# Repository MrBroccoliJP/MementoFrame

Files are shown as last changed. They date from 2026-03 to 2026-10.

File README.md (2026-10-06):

<p align="center">
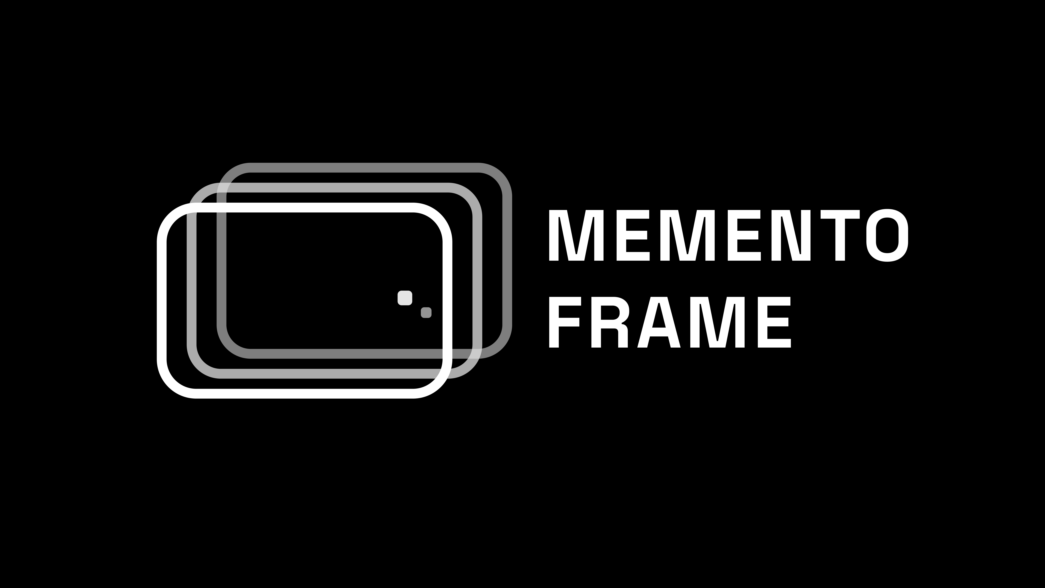
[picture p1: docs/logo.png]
MementoFrame logo
  
</p>

<h1 align="center">MementoFrame</h1>

<p align="center">
  Smart Raspberry Pi photo frame with automatic Wi-Fi/AP fallback, live Spotify integration, weather widgets, GPIO-controlled display power, and a web-based configuration portal.
</p>

<p align="center">
  
  
  
  
</p>

---

## Contents

- [Overview](#overview)
- [Features](#features)
- [Hardware Build](#hardware-build)
  - [Bill of Materials](#bill-of-materials)
  - [3D-Printed Parts](#3d-printed-parts)
  - [GPIO Connections](#gpio-connections)
  - [Wiring](#wiring)
  - [Enclosure Renders](#enclosure-renders)
- [Software Setup](#software-setup)
  - [Frontend Development Mocks](#frontend-development-mocks)
- [Technical Reference](#technical-reference)
- [Credits and License](#credits-and-license)

---

## Overview

MementoFrame is a self-contained smart photo frame platform built around a Raspberry Pi.

The system boots directly into a Chromium kiosk interface while remaining configurable from another device on the same network or on the fallback AP.

### Display Interface

<p align="center">
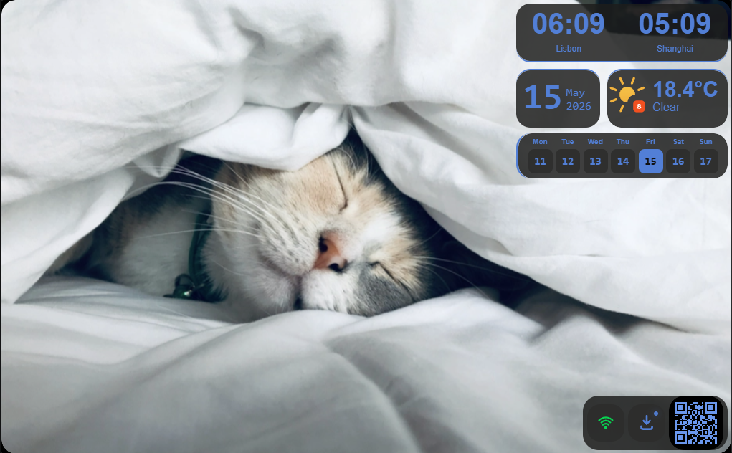
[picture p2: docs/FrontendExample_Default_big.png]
MementoFrame default full-frame photo layout with clocks, current weather, weekly calendar, system controls, and configuration QR code
  
  <br/>
  <strong>Default full-frame view</strong> — photo slideshow, clocks, current weather, weekly calendar, system status, and configuration QR code.
</p>

#### Expanded Widget Layouts

<table>
  <tr>
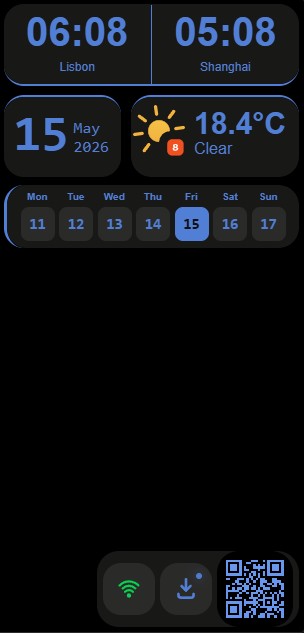
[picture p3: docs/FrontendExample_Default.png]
MementoFrame default widget layout with clocks, date, current weather, weekly calendar, and system controls
    <td align="center"><br/><strong>Default widgets</strong></td>
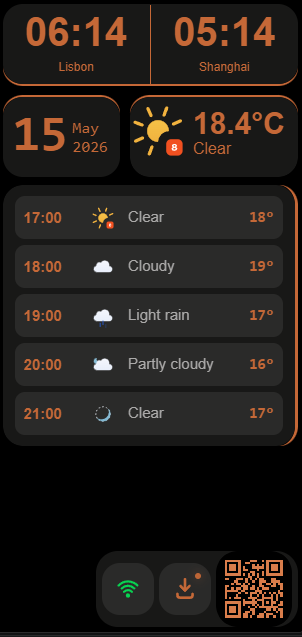
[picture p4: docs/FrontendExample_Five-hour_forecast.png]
MementoFrame expanded five-hour weather forecast layout
    <td align="center"><br/><strong>Five-hour forecast</strong></td>
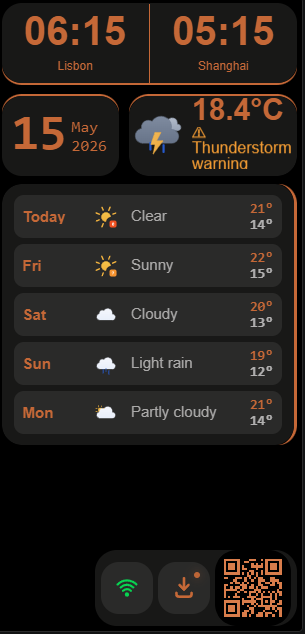
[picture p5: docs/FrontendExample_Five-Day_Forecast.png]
MementoFrame expanded five-day weather forecast layout
    <td align="center"><br/><strong>Five-day forecast*</strong></td>
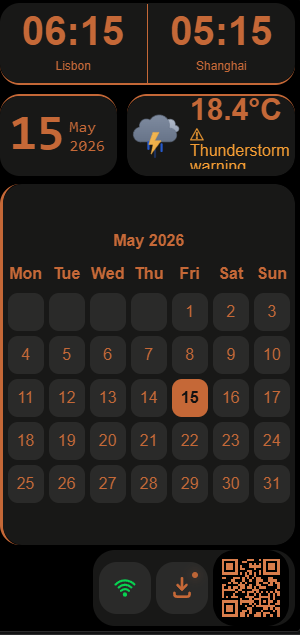
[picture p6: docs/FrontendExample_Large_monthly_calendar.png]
MementoFrame large monthly calendar layout
    <td align="center"><br/><strong>Large monthly calendar</strong></td>
  </tr>
</table>

*The mock environment provides five daily forecast entries for layout testing.
The current production configuration displays three days because that is the
forecast range available from its WeatherAPI.com plan.

#### Full Interface Examples

<p align="center">
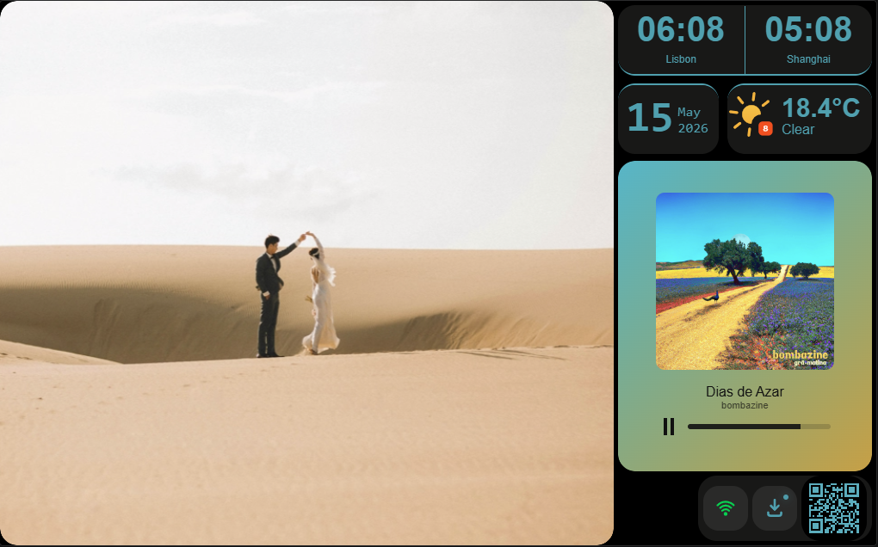
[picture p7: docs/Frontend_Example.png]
Example MementoFrame display interface showing a photo, two clocks, date, weather, Spotify playback, network status, update status, and configuration QR code
  
  <br/>
  <strong>Spotify-focused view</strong> — clocks, current weather, large Spotify playback, system status, and configuration QR code.
</p>

<p align="center">
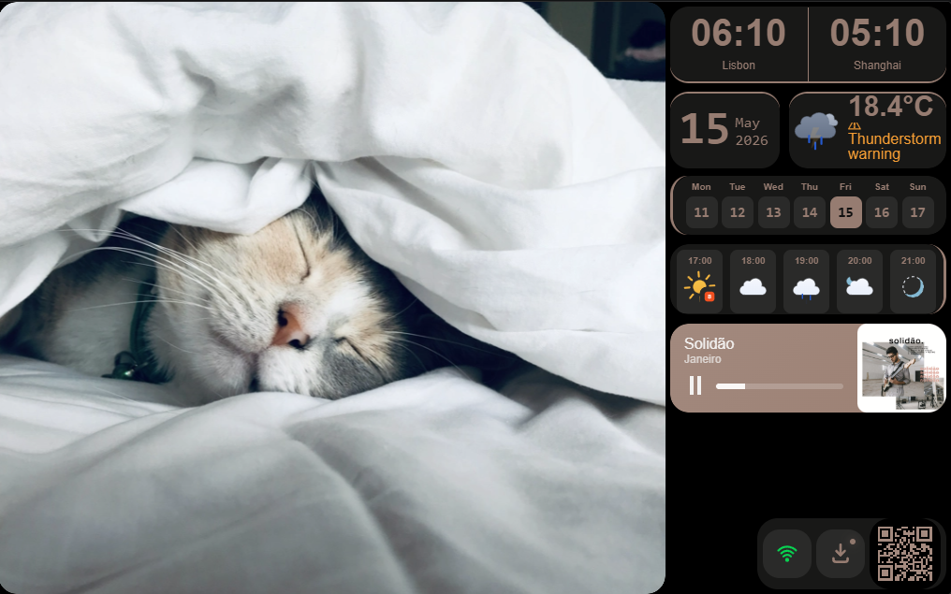
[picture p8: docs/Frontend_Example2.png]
Example MementoFrame display interface showing a photo, clocks, date, weather warning, weekly forecast, hourly forecast, Spotify playback, network status, update status, and configuration QR code
  
  <br/>
  <strong>Forecast and Spotify view</strong> — weather alert, weekly and hourly forecasts, compact Spotify playback, system status, and configuration QR code.
</p>

Displayed widgets and their layout depend on the saved configuration and the
data currently available from connected services.

#### Automatic Layout Modes

MementoFrame chooses layouts automatically according to Spotify playback,
forecast availability, and its current display cycle:

| State | Modes shown |
|---|---|
| Normal display | Weekly calendar by default; compact five-hour forecast once during each five-minute cycle when forecast data is available. |
| Spotify playing | Large Spotify player by default; once during each five-minute cycle it changes to compact Spotify with the weekly calendar and compact five-hour forecast. |
| Expanded mode | Starts after a 30-minute interval and remains active for up to 10 minutes. It rotates between the large five-hour forecast, large five-day forecast, and large monthly calendar; Spotify playback temporarily interrupts it. |
| Forecast unavailable | Forecast modes are skipped and the corresponding weekly or monthly calendar remains visible instead. |

The photo slideshow, clocks, date, current-weather card, network status, update
status, and configuration QR code continue to appear wherever the selected
layout has space for them. The interface also swaps sides once per hour to vary
the presentation and reduce prolonged use of the same screen area.

In the Classic, Classic Flat, and Minimal Sidebar themes, interface accent
colors cycle automatically through a randomized palette. Classic Flat keeps
the Classic layout and materials while removing the colored panel outlines.
When Spotify is playing, the player derives a primary and companion color from
the current album art and applies that palette across the interface.

### Project Photos

<table>
  <tr>
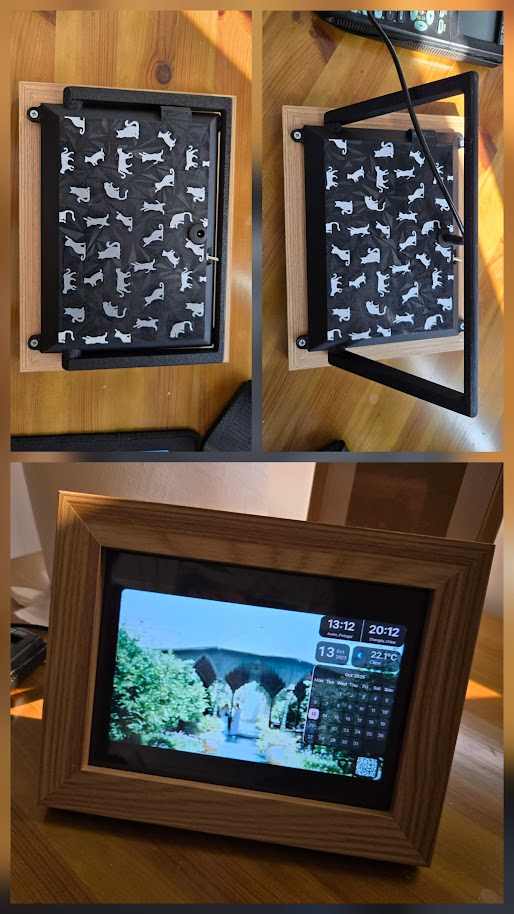
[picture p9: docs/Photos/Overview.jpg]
MementoFrame front and rear overview
    <td align="center"><br/><strong>Front and rear overview</strong></td>
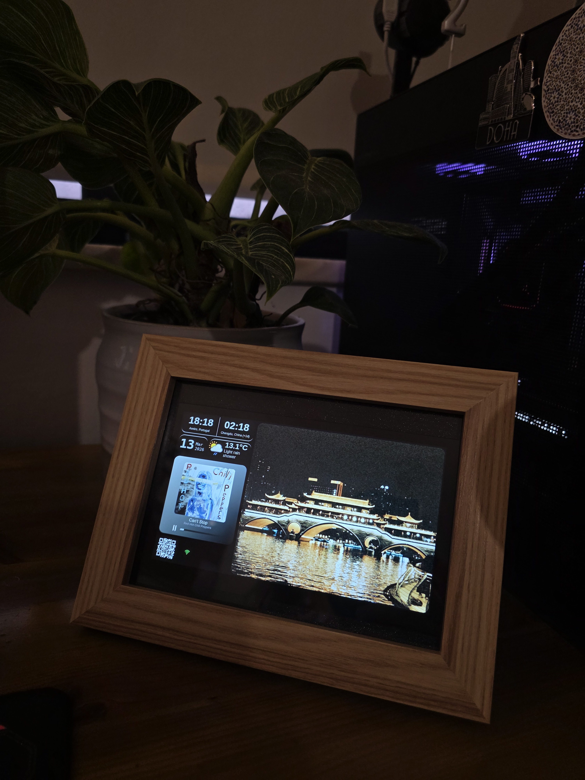
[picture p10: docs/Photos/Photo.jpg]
MementoFrame displaying a photo with widgets and Spotify controls
    <td align="center"><br/><strong>MementoFrame in use</strong></td>
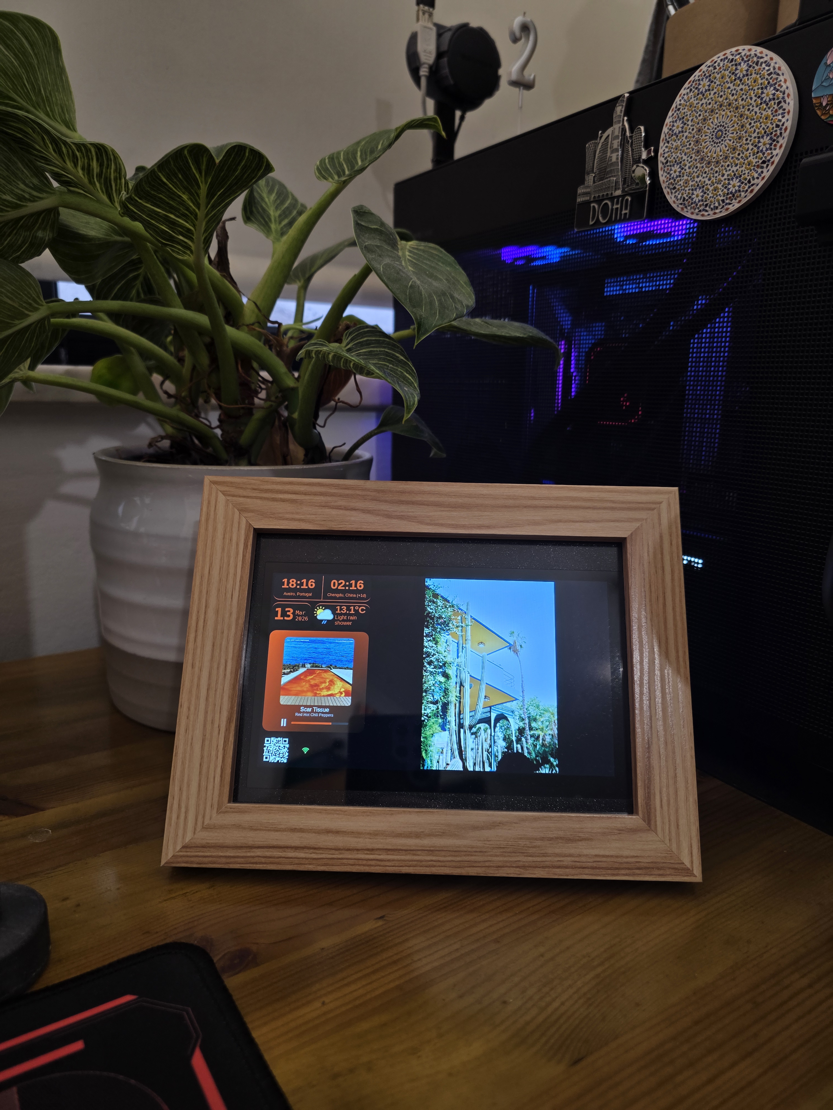
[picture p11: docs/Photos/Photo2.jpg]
MementoFrame displaying a portrait photo with widgets and Spotify controls
    <td align="center"><br/><strong>Portrait photo display</strong></td>
  </tr>
</table>

---

## Features

### Photo Management

- Multi-file photo uploads
- Automatic EXIF rotation handling
- Automatic WebP conversion
- Thumbnail generation
- Persistent slideshow ordering
- Dynamic display reloads via SSE

### Network Management

- Fully managed by NetworkManager
- Automatic fallback AP mode
- SSID: `MementoFrame`
- AP gateway: `192.168.4.1`
- Automatic reconnect probing
- Runtime-only configuration PIN protection

### Display Features

- Fullscreen Chromium kiosk mode
- GPIO-controlled display power
- GPIO brightness pulse control
- Auto on/off schedules
- Dual timezone clocks
- Selectable Classic, Classic Flat, and Minimal Sidebar display themes
- Filled, flat, line, or recolored monochrome forecast icons; current weather and warnings remain filled
- Weather widget with selectable Open-Meteo, WeatherAPI.com, or Google Weather providers
- Spotify album art and playback state

### Weather Providers

WeatherAPI.com was MementoFrame's original and default weather provider. After
inconsistent and inaccurate results were observed for the locations used during
development, Open-Meteo and Google Weather were added as alternatives, with
Open-Meteo becoming the default for new installations. The provider adapters
normalize their different responses into the original MementoFrame weather
flow, allowing the existing current-weather, hourly-forecast, daily-forecast,
UV-index, and icon-rendering code to work across all three providers.

### Updates

- GitHub Releases-based update checks
- Manual update from the configuration portal
- Optional automatic update window
- Persistent user data preservation
- Post-reboot health validation

---

## Hardware Build

### Bill of Materials

The following frame, electronic, and display components are used for one MementoFrame.
Printed parts and their fasteners are listed separately in the next section.

| Component | Quantity | Specification / purpose |
|---|---:|---|
| Wooden photo frame | 1 | Store-bought frame for a 130 × 180 mm (13 × 18 cm, approximately 5 × 7 inch) photo. The supplied 3D files are designed around the dimensions documented below. |
| Raspberry Pi 3B+ | 1 | Main computer running the MementoFrame software. |
| EP-0170 display | 1 | Commonly sold as the GeeekPi 7-inch Raspberry Pi LCD; 1024 × 600 IPS panel. |
| DS3231 RTC module | 1 | Battery-backed real-time clock for retaining the time while disconnected from power. |
| Mini-560 DC-DC buck converter | 2 | Step-down converters configured for 12 V input and 5 V output: one for the display and one for the Raspberry Pi. |
| DC power-filter board | 1 | Filters the incoming DC supply before it reaches the converters and electronics. |
| 2.1 mm panel-mount female DC barrel jack | 1 | Panel-mount power input; select a size matching the power-supply plug. |
| Solderable Micro-USB plug | 1 | Connects the 5 V power-board output to the Raspberry Pi power input. |
| FPC HDMI cable | 1 | Low-profile HDMI connection between the Raspberry Pi and display. |
| Right-angle HDMI-to-FPC adapter | 1 | Display-side adapter. |
| HDMI-to-FPC adapter | 1 | Raspberry Pi-side adapter. |
| MTS-102 mini toggle switch | 1 | Manual power/control switch. |
| SPST DIP or slide switch | 1 (optional) | Initial-setup override that keeps the display enabled before GPIO control is active. |
| Hook-up wire | As required | Power and signal wiring between the boards, connectors, and switch. |

The two HDMI-to-FPC adapters and FPC cable must use the same pin count and
contact orientation. Before connecting the Raspberry Pi or display, adjust
both Mini-560 converters and verify a stable 5 V output with a multimeter.

### 3D-Printed Parts

MementoFrame uses six 3D-printed part designs. One complete assembly requires
one print of each design. Ready-to-print STL files are in [`hardware/stl`](hardware/stl),
and the editable Fusion 360 archive is available at
[`hardware/source/MementoFrame.f3z`](hardware/source/MementoFrame.f3z).

#### Wooden Frame Compatibility

The supplied 3D files were designed for a store-bought wooden frame intended
for a 130 × 180 mm (13 × 18 cm, approximately 5 × 7 inch) photo. A different frame can be used to suit individual
needs or preferences, but the fit must be checked and the 3D models may need to
be adjusted accordingly.

| Measurement | Reference frame |
|---|---:|
| Nominal photo size | 130 × 180 mm (13 × 18 cm / 5 × 7 inches) |
| Visible front opening | Approximately 120 × 170 mm (not important due to the display bezel*) |
| Outside wooden-frame dimensions | 218 × 169 mm |
| Approximate front wooden bezel | 24.25 mm |
| Rear opening for inserting the photo/display | 130 × 181 mm |
| Approximate rear bezel | 20 mm |
| Minimum rear bezel required for back-cover mounting points | 10 mm |
| Overall frame depth | 18 mm |
| Available internal depth | 9.5 mm |
| Glass thickness | 1.6 mm |

*3D changes to the display mounting plate would need to be done to accomodate a different outer frame.

The original glass is reused. The display sits against the glass, with the
printed assembly installed behind it. The original back is discarted.

> **Wall-mounting limitation:** The current design is intended for use with
> the printed stand. It cannot sit flush against a wall because the DC barrel
> jack protrudes from the rear. Wall mounting requires changes to the 3D files
> to relocate or recess the power connector and provide suitable mounting
> points.

#### Assembly Layout

<p align="center">
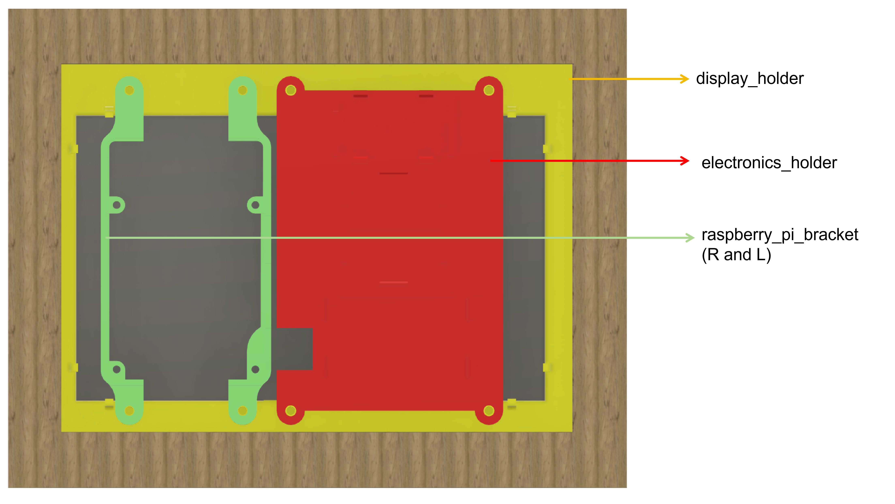
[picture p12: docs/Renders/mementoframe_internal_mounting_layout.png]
MementoFrame internal mounting layout showing the display holder, electronics holder, and Raspberry Pi brackets
  
  <br/>
  <strong>Internal mounting layout</strong> — display holder, electronics holder, and left/right Raspberry Pi brackets.
</p>

The display is secured by integrated clips on the 3D-printed display holder.
The holder uses different side offsets to compensate for the display's uneven
physical bezel and center the visible LCD area within the wooden frame opening.
Display orientation is therefore important: align the thicker and thinner
bezel edges with the corresponding sides of the holder. Before engaging all
clips or closing the frame's metal tabs, inspect the frame from the front and
confirm that the active LCD area—not the outside edge of the display board—is
centered in the visible opening.

The display holder is then retained inside the wooden frame by the frame's
original metal tabs—the same tabs normally used to hold the glass, photo, and
backing board. The display holder therefore needs no adhesive or additional
fasteners of its own.

The back cover sits over the completed electronics assembly and is secured
directly to the rear wooden bezel with four 3 × 10 mm wood screws.

The DC power-filter board, DS3231 RTC module, and both Mini-560 DC-DC buck
converters press-fit into their dedicated positions on the 3D-printed
electronics holder; they do not require separate mounting screws.
The Raspberry Pi itself does not require screws; the left and right brackets clamp the board securely in place.

<p align="center">
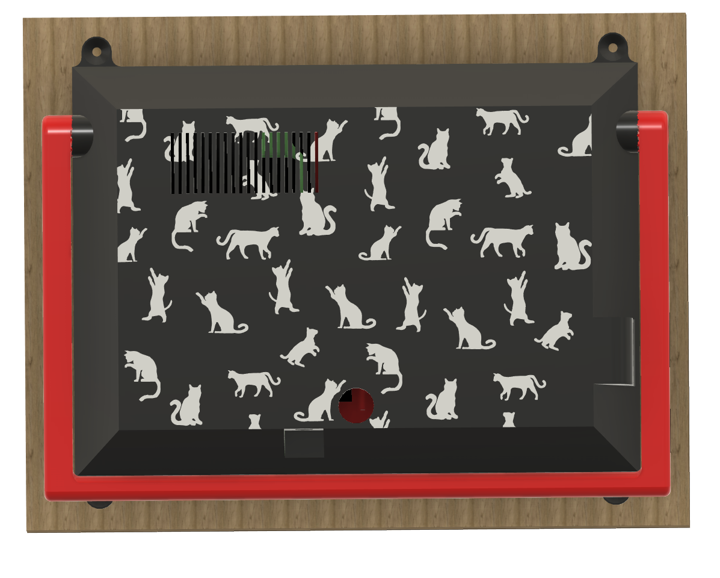
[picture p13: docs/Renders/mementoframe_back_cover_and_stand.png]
MementoFrame rear assembly showing the back cover and stand
  
  <br/>
  <strong>Rear assembly</strong> — installed back cover and stand.
</p>

#### Assembly Hardware

In addition to the printed parts, one complete assembly requires:

| Fastener | Quantity | Used for |
|---|---:|---|
| M3 × 10 mm screws | 8 | Electronics holder and left/right Raspberry Pi brackets |
| 3 × 10 mm wood screws | 4 | Securing the back cover to the wooden frame |
| 5 × 10 mm wood screws or M5 × 10 mm screws | 2 | Attaching the stand |

Use the fastener type appropriate for the stand mounting holes and the material
the screws engage. Do not overtighten screws against the printed parts.

#### Parts to Print

| Part | STL file | Quantity | Purpose |
|---|---|---:|---|
| Display holder | [`display_holder.stl`](hardware/stl/display_holder.stl) | 1 | Holds the display with integrated clips. Its side offsets compensate for the uneven display bezel and center the visible LCD. The complete holder is retained by the wooden frame's original metal tabs. |
| Electronics holder | [`electronics_holder.stl`](hardware/stl/electronics_holder.stl) | 1 | Press-fit mounting for both DC buck converters, the power-filter board, and the RTC module; also organizes the wiring. |
| Raspberry Pi brackets | [`raspberry_pi_bracket_L.stl`](hardware/stl/raspberry_pi_bracket_L.stl) and [`raspberry_pi_bracket_R.stl`](hardware/stl/raspberry_pi_bracket_R.stl) | 1 left, 1 right | Secures the Raspberry Pi while preserving connector access and airflow. |
| Back cover | [`back_cover.stl`](hardware/stl/back_cover.stl) | 1 | Protects the electronics and wiring while providing ventilation and access openings. Secures to the wooden frame with four 3 × 10 mm wood screws. |
| Stand | [`stand.stl`](hardware/stl/stand.stl) | 1 | Supports the frame at a suitable viewing angle and attaches with two screws. |

### GPIO Connections

| GPIO | Purpose |
|---:|---|
| GPIO 20 | Brightness UP pulse |
| GPIO 21 | Brightness DOWN pulse |
| GPIO 26 | Screen power enable |

### Wiring

The diagram below shows the power distribution, display controls, RTC wiring,
and HDMI connection. The completed wiring photo can be used as a reference for
component placement and cable routing.

<p align="center">
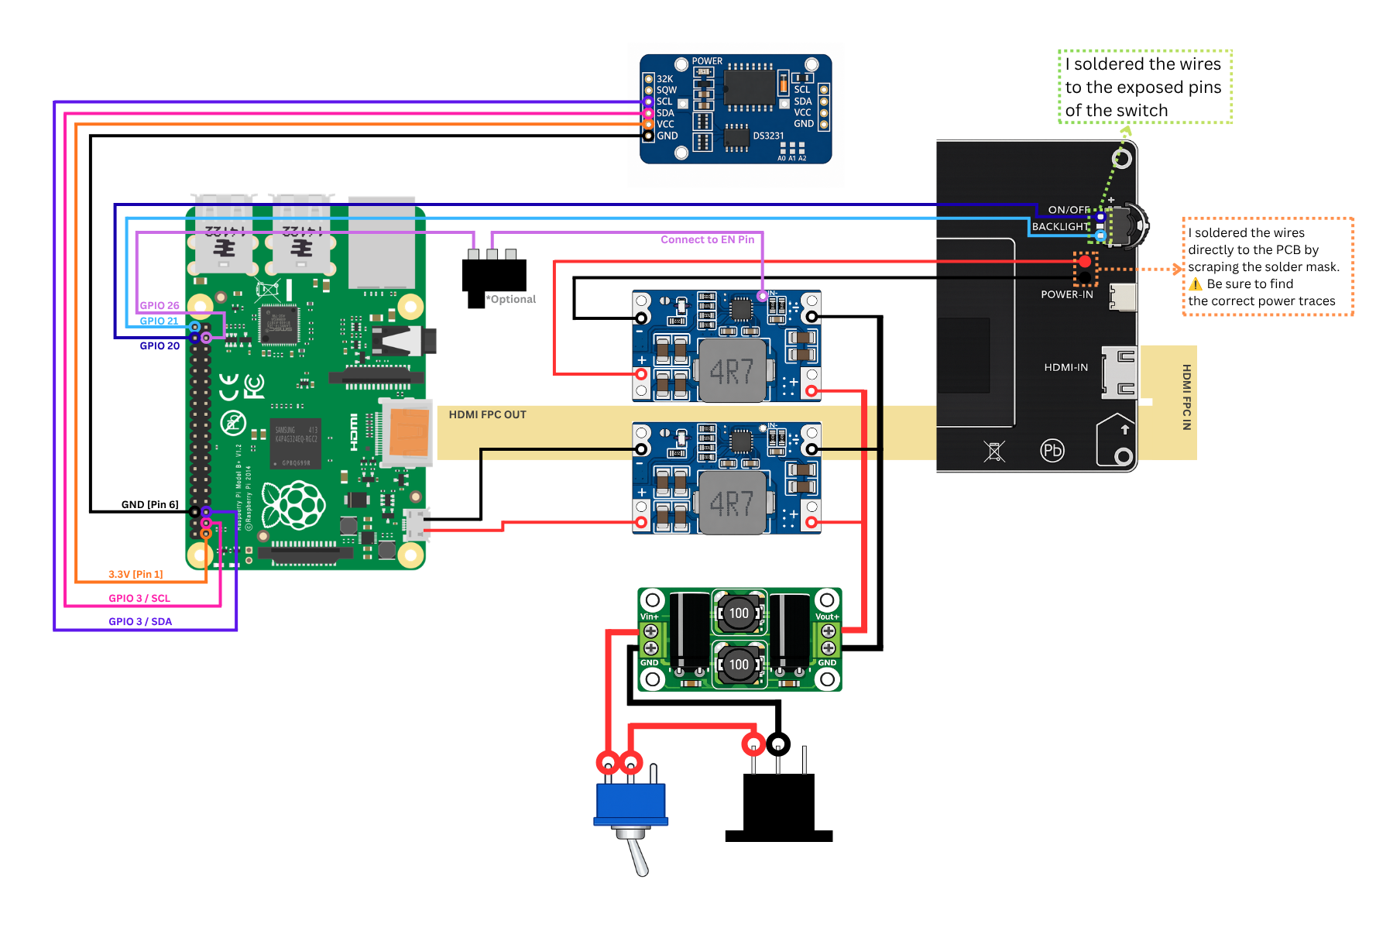
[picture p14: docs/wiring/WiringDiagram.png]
MementoFrame wiring diagram for the Raspberry Pi, display, RTC, buck converters, optional display-enable switch, power filter, toggle switch, and barrel jack
  
  <br/>
  <strong>Wiring diagram</strong>
</p>

<p align="center">
  Completed MementoFrame internal wiring and electronics installation
  <br/>
  <strong>Completed wiring and component placement</strong>
</p>

#### Connection Summary

| Connection | Details |
|---|---|
| Power input | The 12 V supply enters through the barrel jack and MTS-102 switch, then passes through the DC power-filter board. |
| 5 V power | The filtered 12 V input feeds both Mini-560 converters. One converter powers the Raspberry Pi and the other powers the display. |
| RTC | Connect the DS3231 to Raspberry Pi 3.3 V, ground, I²C SDA, and I²C SCL. |
| Display controls | Connect display power and brightness controls to GPIO 26, GPIO 20, and GPIO 21 as labelled in the diagram. |
| Optional display-enable override | Install the optional DIP/slide switch in the display-enable circuit as shown. It keeps the display powered during initial assembly and software installation. |
| Video | The FPC HDMI cable links the Raspberry Pi HDMI output to the display HDMI input through the two HDMI-to-FPC adapters. |

#### Optional First-Boot Display Override

The display-enable GPIO starts inactive before the MementoFrame service is
installed and running, which would otherwise leave the screen switched off.
The optional DIP/slide switch provides a manual override that keeps the display
enabled while assembling the frame, installing the operating system, and
setting up the software.

Close the override switch for initial setup. Once GPIO display control is
installed and confirmed to work, open the switch to return control to the
Raspberry Pi. The switch can remain installed for future troubleshooting.

> **Important:** Disconnect power while assembling the wiring. Set and verify
> both buck-converter outputs at 5 V before connecting the Raspberry Pi or
> display, and confirm polarity with a multimeter. The display control wires
> are soldered directly to exposed PCB points, and trace locations can differ
> between display revisions. Trace them from the USB-C connector and verify the
> circuit before soldering. Never scrape, probe, or solder an energized PCB.

### Enclosure Renders

<table>
  <tr>
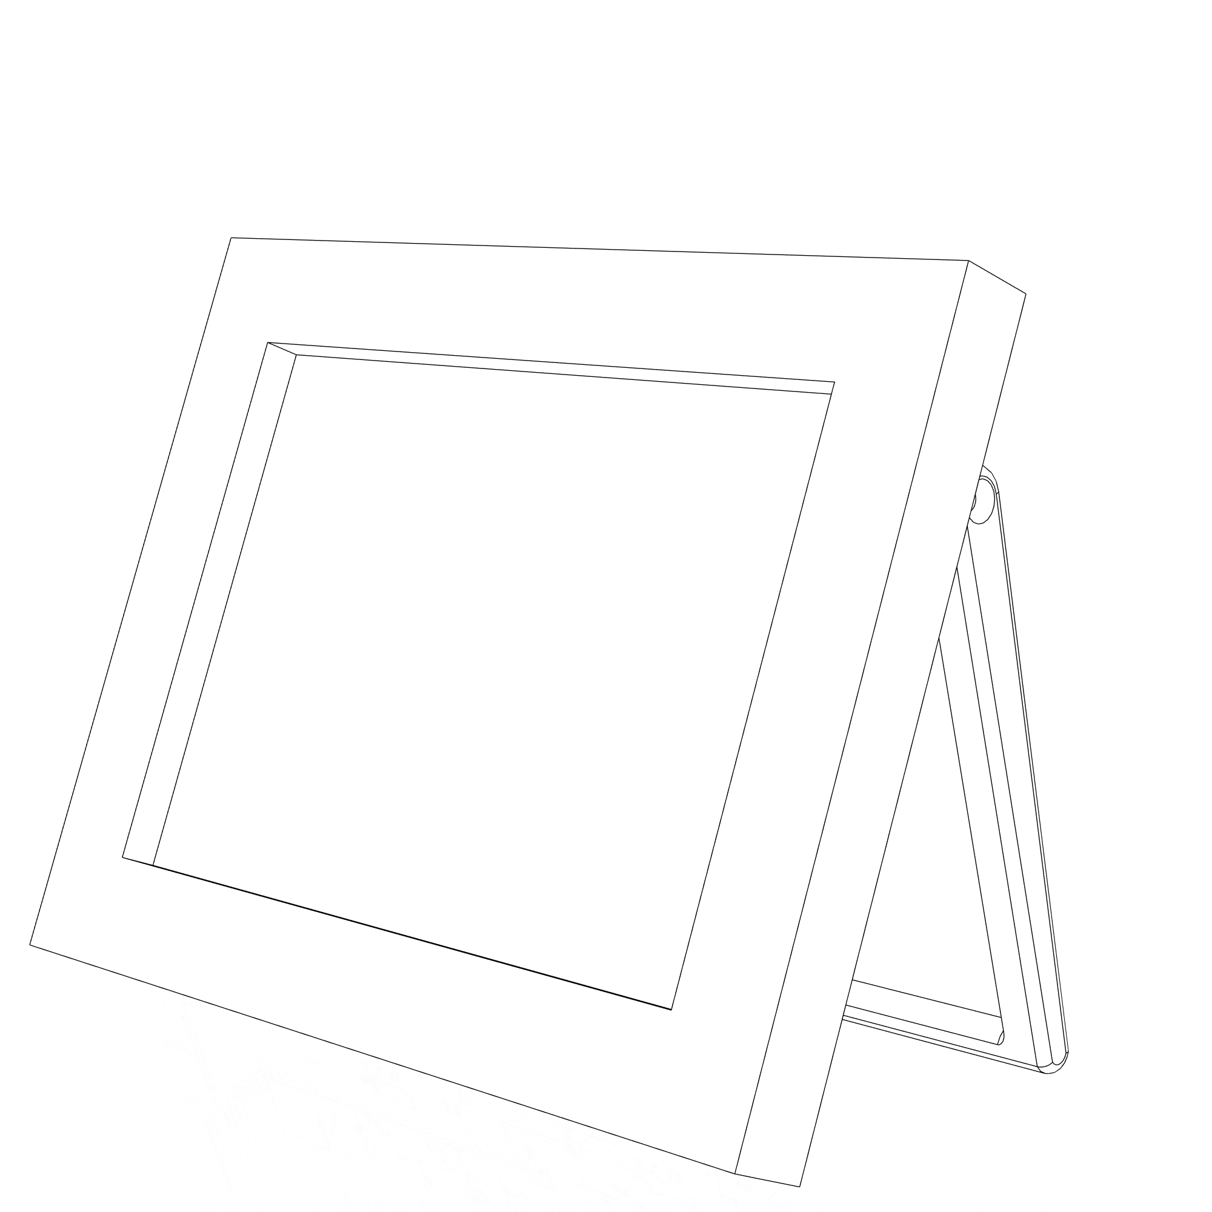
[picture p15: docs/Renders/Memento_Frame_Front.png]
MementoFrame front view
    <td align="center"><br/><strong>Front</strong></td>
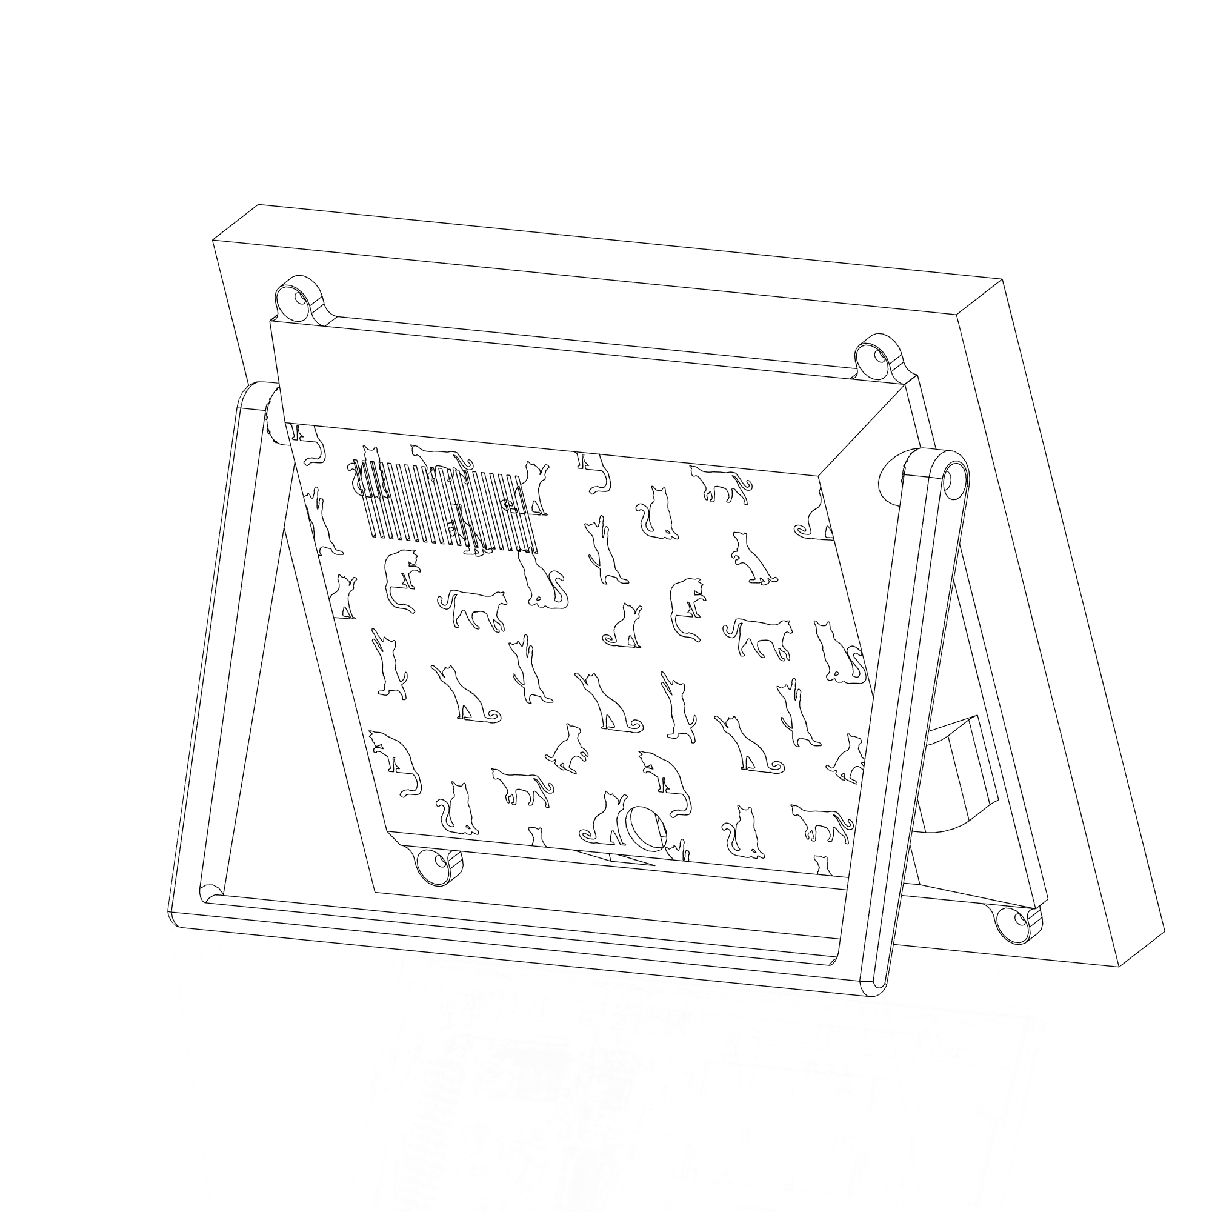
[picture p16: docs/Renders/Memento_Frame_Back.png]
MementoFrame back view
    <td align="center"><br/><strong>Back</strong></td>
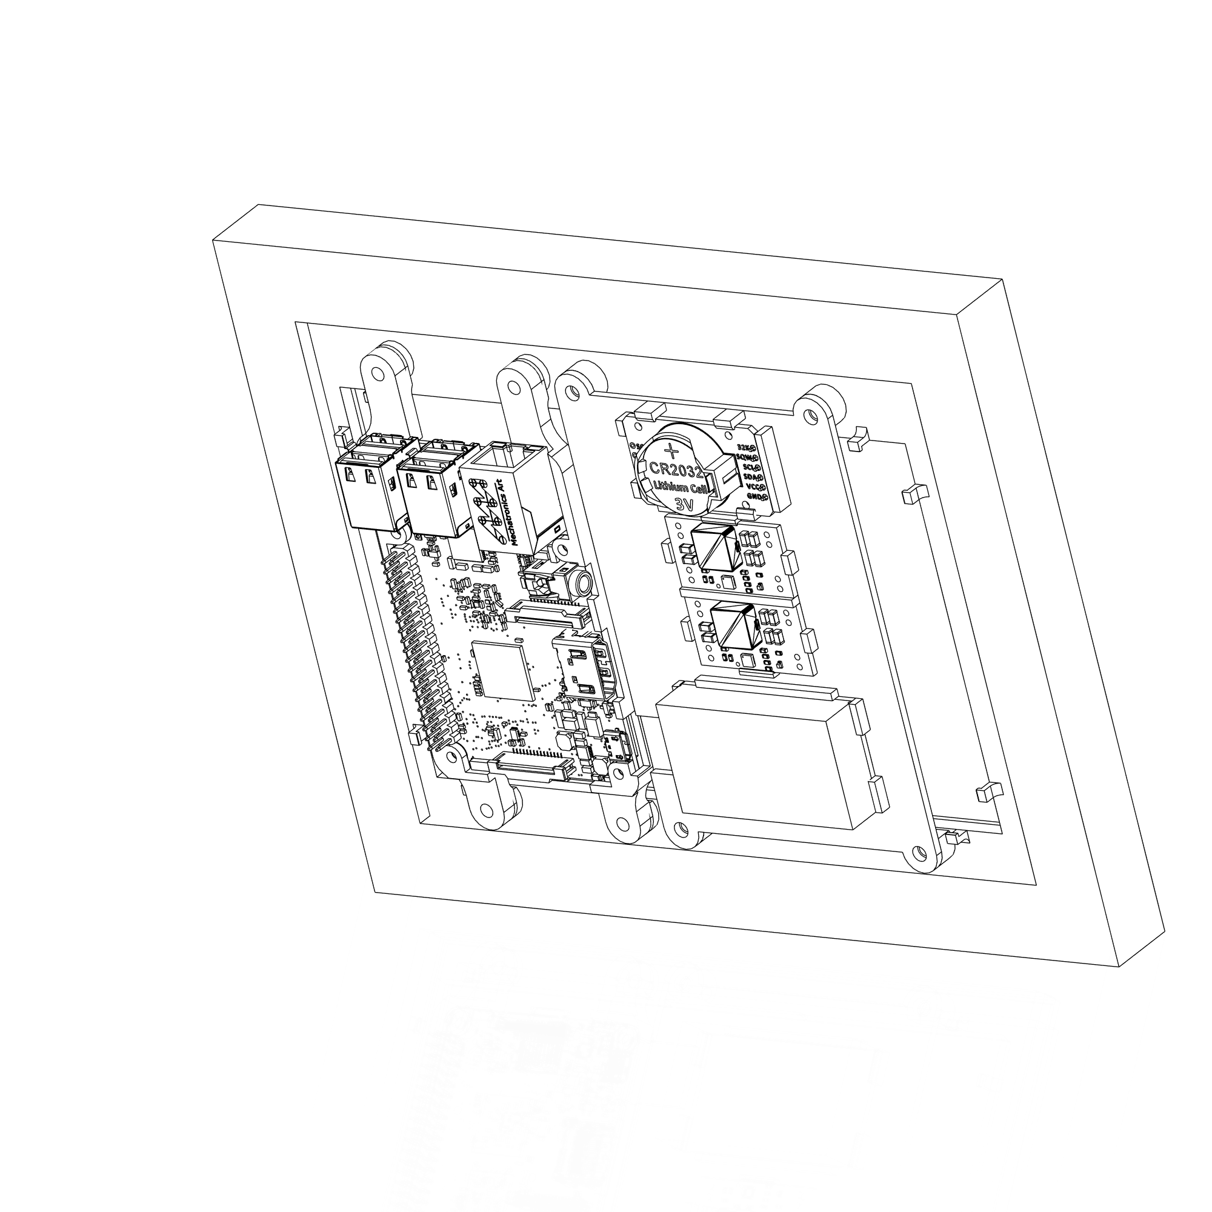
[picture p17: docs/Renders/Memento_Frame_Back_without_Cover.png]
MementoFrame back view without cover
    <td align="center"><br/><strong>Back without cover</strong></td>
  </tr>
  <tr>
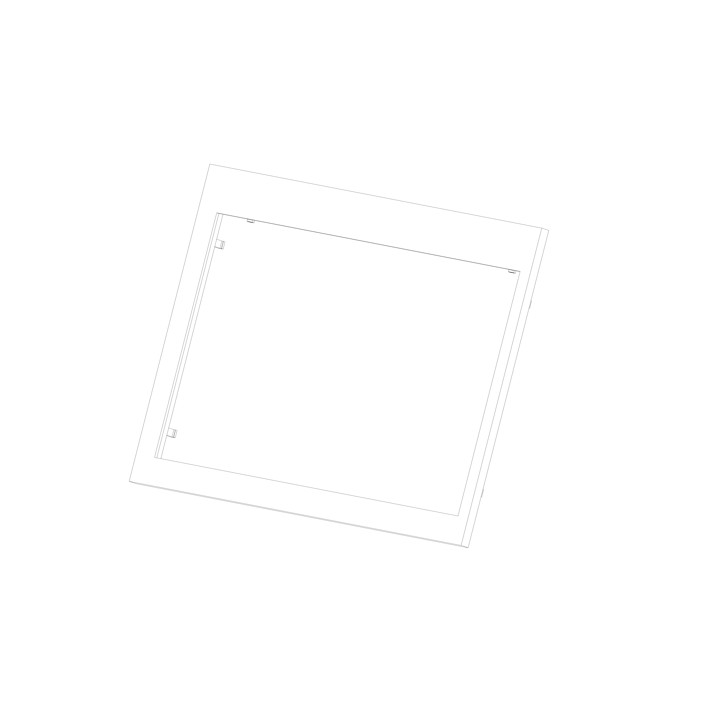
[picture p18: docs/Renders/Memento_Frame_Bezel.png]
MementoFrame display holder
    <td align="center"><br/><strong>Display holder</strong></td>
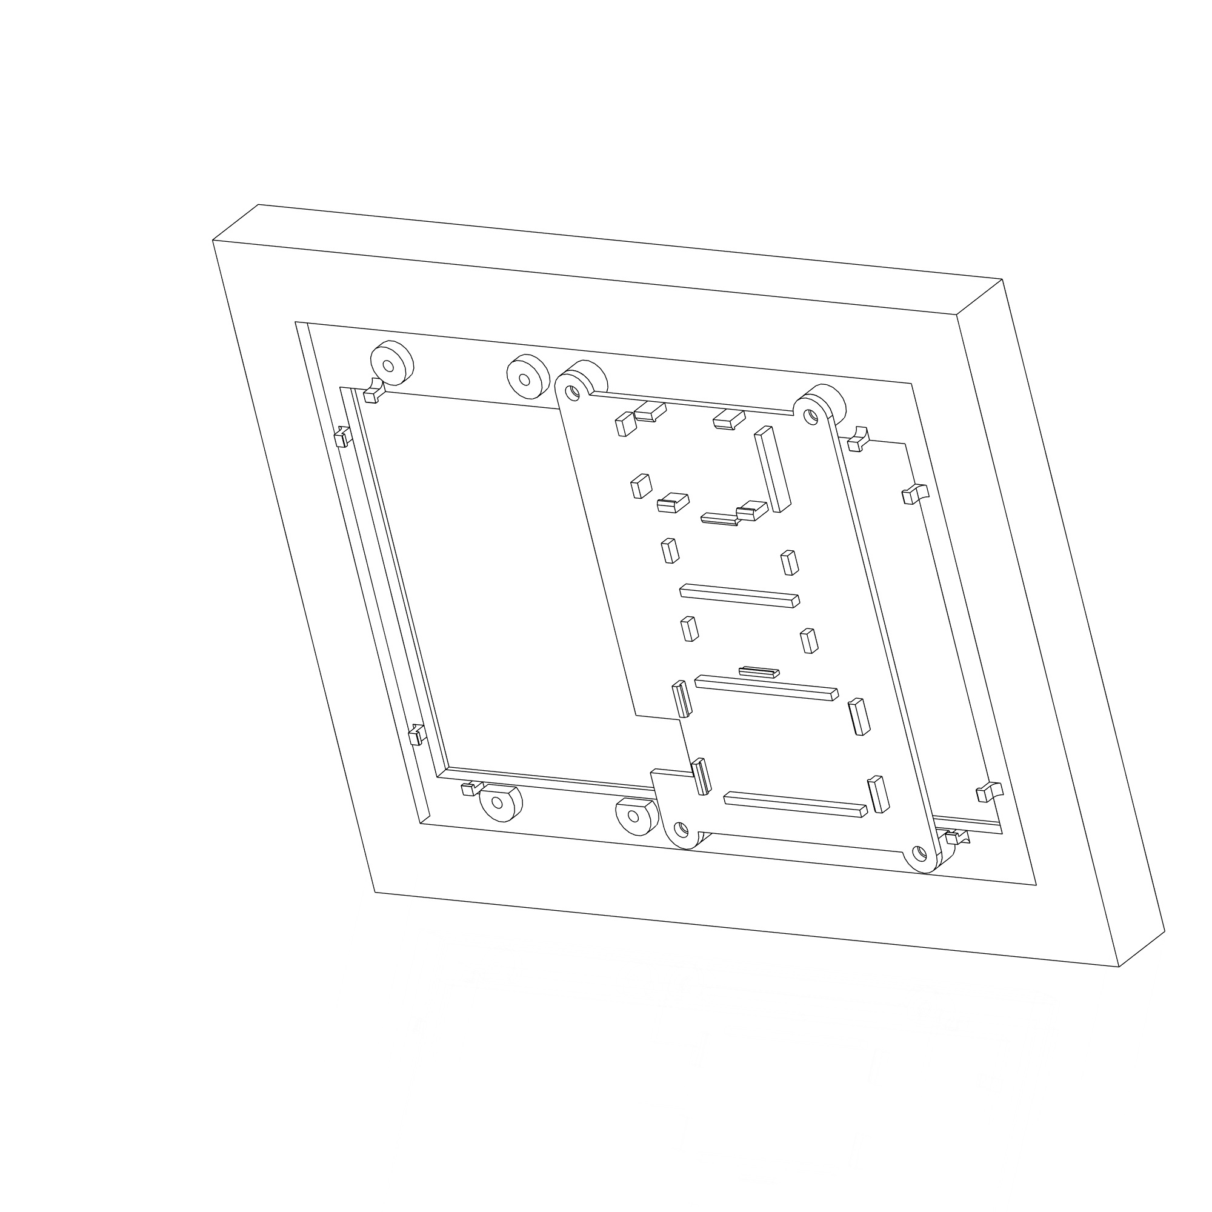
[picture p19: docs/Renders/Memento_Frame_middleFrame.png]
MementoFrame middle frame
    <td align="center"><br/><strong>Middle frame</strong></td>
    <td></td>
  </tr>
</table>

---

## Software Setup

### Software Requirements

- Raspberry Pi OS Lite 13 (Trixie), 32-bit or 64-bit
- Python 3.11+
- NetworkManager
- Chromium

#### 32-bit and 64-bit Support

MementoFrame supports both the 32-bit and 64-bit editions of Raspberry Pi OS Lite Trixie.

- **64-bit** supports the full KMS graphics driver.
- **32-bit** uses the FKMS compatibility driver for the current display setup.

Full KMS support is still being tested. Two frames using slightly different revisions of the same display controller PCB produced different results, so FKMS may be the safer option if the display is blank or unstable. See [Prepare the SD Card](INSTALL.md#prepare-the-sd-card) for OS selection and setup instructions.

### Installation

Full setup instructions, configuration details, and troubleshooting guidance are available in [INSTALL.md](INSTALL.md).

Quick install:

```bash
curl -fL https://github.com/MrBroccoliJP/MementoFrame/releases/latest/download/install.sh -o install.sh
sudo bash install.sh
```

### First Connection and Fallback AP

When no known Wi-Fi network is available, MementoFrame automatically enables a local configuration hotspot.

| Setting | Value |
|---|---|
| SSID | `MementoFrame` |
| Gateway | `192.168.4.1` |
| Dashboard | `http://192.168.4.1:5000` |

#### AP Flow

```text
No Wi-Fi detected
        │
        ▼
Enable NetworkManager AP profile
        │
        ▼
Generate temporary config PIN
        │
        ▼
User connects to MementoFrame AP
        │
        ▼
Enter PIN on dashboard
        │
        ▼
Configure Wi-Fi credentials
        │
        ▼
Reconnect to client network
```

### Frontend Development Mocks

The [`dev`](dev) folder contains local mock applications for developing the
frontend and testing features on a desktop without a Raspberry Pi, GPIO
hardware, or live external services. The mocks mirror the production routes
and share state so the display and configuration portal can be tested together.

The mock environment supports:

- Display UI and configuration portal development
- Wi-Fi client and fallback AP simulation
- Configuration PIN flows
- Mock or real Spotify and weather data
- Forced-time testing for clocks and schedules
- Photo upload, deletion, and SSE reload behavior
- Screen state and software-update UI states

Run both mock services from the repository root:

```bash
python dev/run_mocks.py
```

| Interface | URL |
|---|---|
| Mock configuration portal | `http://localhost:5000` |
| Mock display UI | `http://localhost:5001` |
| Mock controls | `http://localhost:5001/mock` |

Mock update operations never install files, restart the computer, or reboot it.
Mock-only runtime state is stored under `dev/runtime/`. See
[`dev/dev_instructions.md`](dev/dev_instructions.md) for dependency setup,
available controls, test scenarios, and individual mock endpoints.

---

## Technical Reference

### Architecture

```text
                          ┌────────────────────┐
                          │ Chromium Kiosk UI  │
                          └─────────┬──────────┘
                                    │
                                    ▼
                    ┌──────────────────────────────┐
                    │ display_service.py            │
                    │ mementoframe-display.service  │
                    │ Port 5001                     │
                    └─────────┬────────────────────┘
                              │
          ┌───────────────────┼───────────────────┐
          │                   │                   │
          ▼                   ▼                   ▼
    Spotify API      Weather providers      GPIO screen control
                     |- Open-Meteo
                     |- WeatherAPI.com
                     `- Google Weather

                    ┌──────────────────────────────┐
                    │ config_portal_service.py      │
                    │ mementoframe-config.service   │
                    │ Port 5000                     │
                    └─────────┬────────────────────┘
                              │
                              ▼
                   Config, Wi-Fi setup, photos,
                   Spotify auth, update controls

                    ┌──────────────────────────────┐
                    │ network_manager_service.py    │
                    │ mementoframe-network.service  │
                    └─────────┬────────────────────┘
                              │
               Wi-Fi connected / fallback AP mode
```

### Runtime Services

MementoFrame uses separate services so each part can be logged, restarted, and debugged independently.

| systemd service | Runtime file | Port | Purpose |
|---|---|---:|---|
| `mementoframe-config.service` | `config_portal_service.py` | `5000` | Admin/configuration portal. |
| `mementoframe-display.service` | `display_service.py` | `5001` | Display frontend server and local widget API. |
| `mementoframe-network.service` | `network_manager_service.py` | — | Wi-Fi/AP fallback watchdog. |
| `mementoframe-kiosk.service` | Chromium | — | Fullscreen display browser. |
| `mementoframe-updater.service` + `.timer` | `updater.py autoupdate` | — | Runs startup/hourly update work and clears pending-restart state only after post-reboot health checks pass. |

### Project Structure

```text
MementoFrame/
├── dev/
│   ├── dev_instructions.md
│   ├── mock_config_portal_service.py
│   ├── mock_display_service.py
│   ├── mock_shared.py
│   ├── mock_updater.py
│   └── run_mocks.py
├── docs/
│   ├── Photos/
│   ├── Renders/
│   ├── Wiring/
│   ├── Frontend_Example.png
│   ├── Frontend_Example2.png
│   ├── FrontendExample_Five-hour_forecast.png
│   ├── FrontendExample_Five-Day_Forecast.png
│   ├── FrontendExample_Large_monthly_calendar.png
│   ├── FrontendExample_Default.png
│   ├── FrontendExample_Default_big.png
│   └── logo.png
├── hardware/
│   ├── source/
│   │   └── MementoFrame.f3z
│   └── stl/
├── mementoframe/
│   ├── config_portal_service.py
│   ├── display_service.py
│   ├── network_manager_service.py
│   ├── updater.py
│   ├── version_info.py
│   ├── requirements.txt
│   ├── config.json
│   ├── runtime/
│   ├── resources/
│   │   ├── assets/
│   │   └── userdata/
│   │       ├── Photos/
│   │       └── cache/
│   ├── static/
│   └── templates/
├── INSTALL.md
└── README.md
```

### Main Endpoints

#### Config portal — port `5000`

| Endpoint | Description |
|---|---|
| `/` | Main configuration dashboard |
| `/upload` | Upload photos |
| `/delete_selected_photos` | Remove photos |
| `/save_clock_settings` | Save clock configuration |
| `/save_appearance_settings` | Save display theme and forecast icon style |
| `/save_display_settings` | Save brightness settings |
| `/save_auto_power` | Save power schedule |
| `/save_weather_api` | Save Open-Meteo, WeatherAPI, or Google Weather configuration |
| `/weather/geocode` | Parse a configured city/region/country into coordinates |
| `/update/status` | Return updater state |
| `/update/check` | Check for updates |
| `/update/install` | Start update |
| `/update/reinstall` | Reinstall the configured channel's latest release |
| `/spotify/connect` | Start Spotify OAuth |
| `/spotify/manual` | Finish Spotify OAuth |
| `/versions` | Return version metadata |
| `/health` | Config portal health check |

#### Display service — port `5001`

| Endpoint | Description |
|---|---|
| `/` | Render display frontend |
| `/spotify.json` | Spotify playback metadata |
| `/weather.json` | Current weather |
| `/status.json` | Network mode and IP |
| `/config/stream` | SSE reload stream |
| `/screen/on` | Enable screen GPIO |
| `/screen/off` | Disable screen GPIO |
| `/update_status.json` | Read-only update state for display UI |
| `/versions` | Return version metadata |
| `/health` | Display service health check |

### Runtime Data

| Path | Purpose |
|---|---|
| `resources/userdata/Photos/full/` | Full-size converted photos |
| `resources/userdata/Photos/thumbs/` | Generated thumbnails |
| `resources/userdata/cache/.cache_spotify` | Spotify OAuth cache |
| `runtime/config_portal_pin.json` | Temporary AP-mode PIN |
| `runtime/update_state.json` | Update lifecycle state |
| `config.json` | User configuration |
| `.env` | Local secrets and optional update token |

### Versioning

Versions are exposed through `/versions` and defined in `version_info.py`.

MementoFrame uses a composite version:

```text
release.frontend.config.display.network.updater
```

Example:

```text
v1.25.22.21.21.13
```

Meaning:

| Segment | Meaning |
|---:|---|
| `1` | Release counter |
| `25` | Frontend version |
| `22` | Config portal version |
| `21` | Display service version |
| `21` | Network manager version |
| `13` | Updater version |

The updater compares the full composite version from GitHub release tags.

### Useful Logs

```bash
journalctl -u mementoframe-config.service -f
journalctl -u mementoframe-display.service -f
journalctl -u mementoframe-network.service -f
journalctl -u mementoframe-kiosk.service -f
journalctl -u mementoframe-updater.service -n 80 --no-pager
```

---

## Credits and License

### License

Creative Commons Attribution-NonCommercial 4.0 International

[http://creativecommons.org/licenses/by-nc/4.0/](http://creativecommons.org/licenses/by-nc/4.0/)

### Author

João Fernandes — 2026

### Acknowledgements

Special thanks to:

<table>
  <tr>
    <td align="center" width="220">
      <a href="https://meteocons.com/">
        Meteocons
        <br/><strong>Meteocons</strong>
      </a>
    </td>
    <td>Weather icons used by the MementoFrame display interface.</td>
  </tr>
  <tr>
    <td align="center" width="220">
      <a href="https://open-meteo.com/en/docs">
        Open-Meteo
        <br/><strong>Open-Meteo</strong>
      </a>
    </td>
    <td>Default keyless provider for current conditions and hourly and daily forecasts.</td>
  </tr>
  <tr>
    <td align="center" width="220">
      <a href="https://developers.google.com/maps/documentation/weather">
        Google
        <br/><strong>Google Weather API</strong>
      </a>
    </td>
    <td>Optional provider for current conditions, hourly and daily forecasts, and public weather alerts.</td>
  </tr>
  <tr>
    <td align="center" width="220">
      <a href="https://www.weatherapi.com/">
        WeatherAPI.com
      </a>
    </td>
    <td>Original MementoFrame weather provider; still supported for current conditions, forecasts, astronomy data, and weather alerts.</td>
  </tr>
  <tr>
    <td align="center" width="220">
      <a href="https://www.spotify.com/">
        Spotify
      </a>
    </td>
    <td>Playback information, album artwork, and music integration used by the MementoFrame display interface.</td>
  </tr>
  <tr>
    <td align="center" width="220">
      <a href="https://github.com/davidshimjs/qrcodejs">
        <strong>QRCode.js</strong>
      </a>
    </td>
    <td>Dependency-free MIT-licensed QR encoder used to generate the local configuration-portal QR code. MementoFrame applies its own connected, rounded canvas renderer to the generated matrix.</td>
  </tr>
</table>

### Demo Image Attributions

These images are included only as demo/development placeholders for MementoFrame.

Images sourced from Unsplash under the Unsplash License:
https://unsplash.com/license

#### Included Images

- `erik-jan-leusink-IbPxGLgJiMI-unsplash.jpg` — Photo by Erik-Jan Leusink — https://unsplash.com/@erikjanl
- `kate-stone-matheson-uy5t-CJuIK4-unsplash.jpg` — Photo by Kate Stone Matheson — https://unsplash.com/@kstonematheson
- `ryoji-iwata-X53e51WfjIE-unsplash.jpg` — Photo by Ryoji Iwata — https://unsplash.com/@ryoji__iwata
- `ray-hennessy-MH_psben7HE-unsplash.jpg` — Photo by Ray Hennessy — https://unsplash.com/@rayhennessy
- `tanya-barrow-AobgShFe_ks-unsplash.jpg` — Photo by Tanya Barrow — https://unsplash.com/@tanyabarrow
- `bin-thieu-ILEzY3D9jbQ-unsplash.jpg` — Photo by Bin Thieu — https://unsplash.com/@binthieu
- `brooke-balentine-ta4hTTz7ipw-unsplash.jpg` — Photo by Brooke Balentine — https://unsplash.com/@brookebalentine
- `microsoft-copilot-o2MBk6J-qc-unsplash.jpg` — Photo by Microsoft 365 — https://unsplash.com/@microsoft365
- `jason-leung-TxhDR5I-sUg-unsplash.jpg` — Photo by Jason Leung — https://unsplash.com/@ninjason

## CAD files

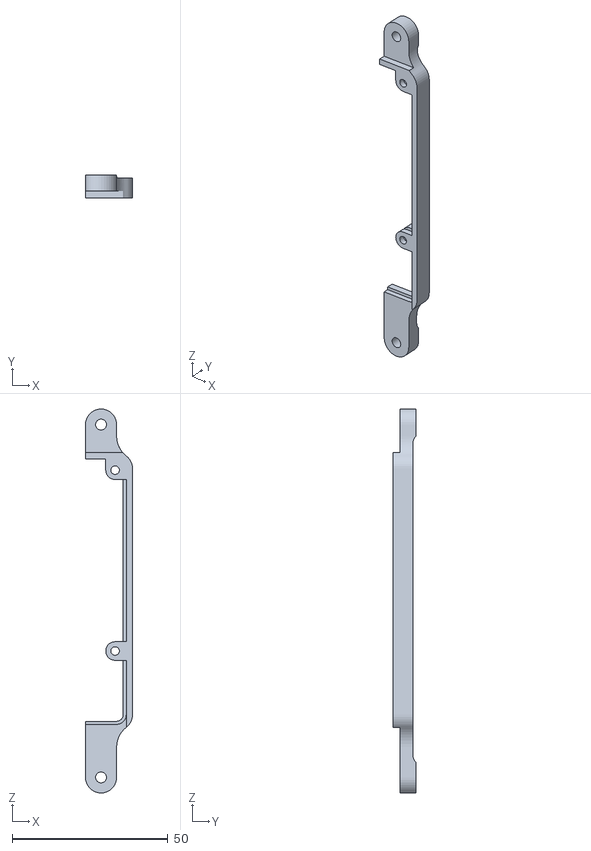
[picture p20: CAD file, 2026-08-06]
hardware/stl/raspberry_pi_bracket_L.stl
15.1 x 7.43 x 123.1

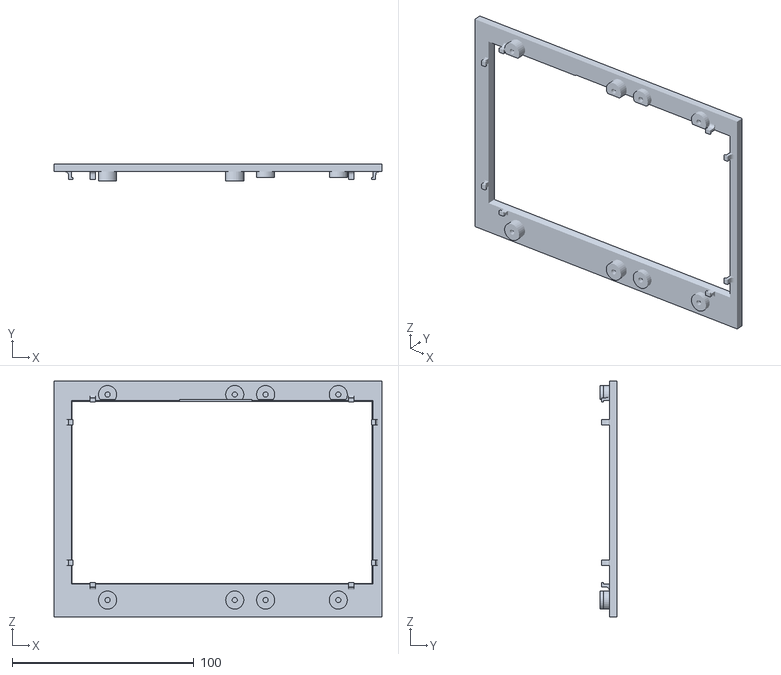
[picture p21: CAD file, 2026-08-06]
hardware/stl/display_holder.stl
180.6 x 9.51 x 129.9

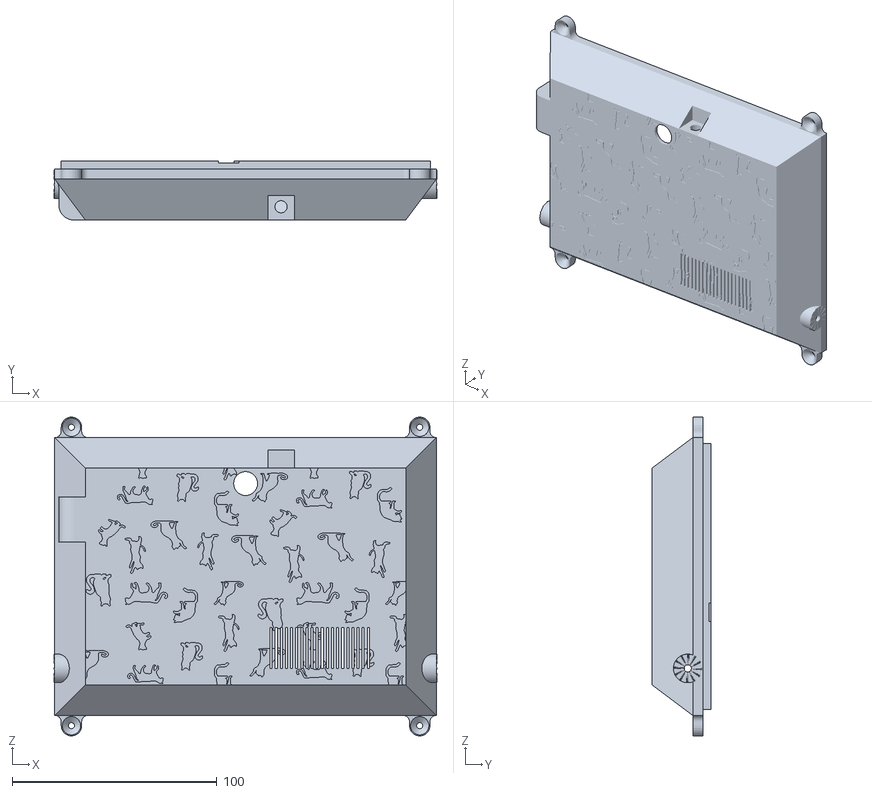
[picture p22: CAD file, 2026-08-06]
hardware/stl/back_cover.stl
187.2 x 28.9 x 155.8

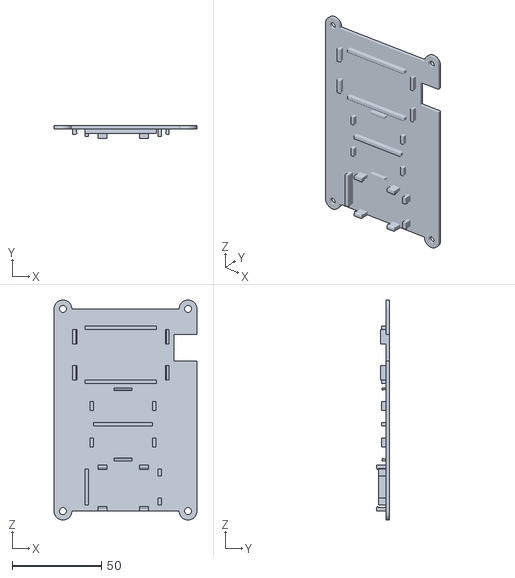
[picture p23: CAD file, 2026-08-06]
hardware/stl/electronics_holder.stl
80.0 x 7.47 x 123.1

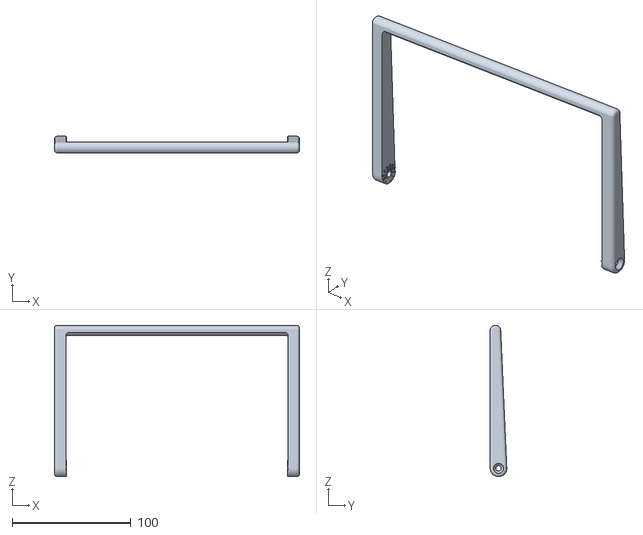
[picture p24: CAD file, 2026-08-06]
hardware/stl/stand.stl
206.6 x 14.0 x 127.5

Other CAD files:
hardware/stl/raspberry_pi_bracket_R.stl

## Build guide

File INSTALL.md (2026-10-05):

# MementoFrame Installation Guide

Set up MementoFrame on Raspberry Pi OS Lite using the automatic installer, then finish the setup from the frame's web dashboard.

## Quick Start

| Step | What to do |
|---:|---|
| **1** | [Prepare the microSD card](#prepare-the-sd-card) and enable SSH in Raspberry Pi Imager. |
| **2** | Start the Pi, connect through SSH, and run the [automatic installer](#automatic-installation-recommended). |
| **3** | Let the Raspberry Pi reboot, then open the [configuration dashboard](#post-install-configuration). |
| **4** | Configure WeatherAPI, optional Spotify integration, Wi-Fi, display settings, and photos. |

> **Recommended path:** use the automatic installer. The [manual installation](#manual-installation-advanced) and [technical reference](#automatic-installation-options-and-technical-reference) are available later in this guide.

---

## Prepare the SD Card

Use [Raspberry Pi Imager](https://www.raspberrypi.com/software/) to install Raspberry Pi OS and prepare the Pi for a headless setup—without connecting a keyboard, mouse, or separate monitor.

1. Insert the microSD card into your computer and open Raspberry Pi Imager.
2. Under **Device**, select **Raspberry Pi 3** for the tested Raspberry Pi 3B+.
3. Under **OS**, select **Raspberry Pi OS (other)**, then choose **Raspberry Pi OS Lite (64-bit)** or **Raspberry Pi OS Lite (32-bit)**.
4. Select the microSD card under **Storage**.
5. Open **Customisation**, complete the settings below, and write the card.

<table>
  <tr>
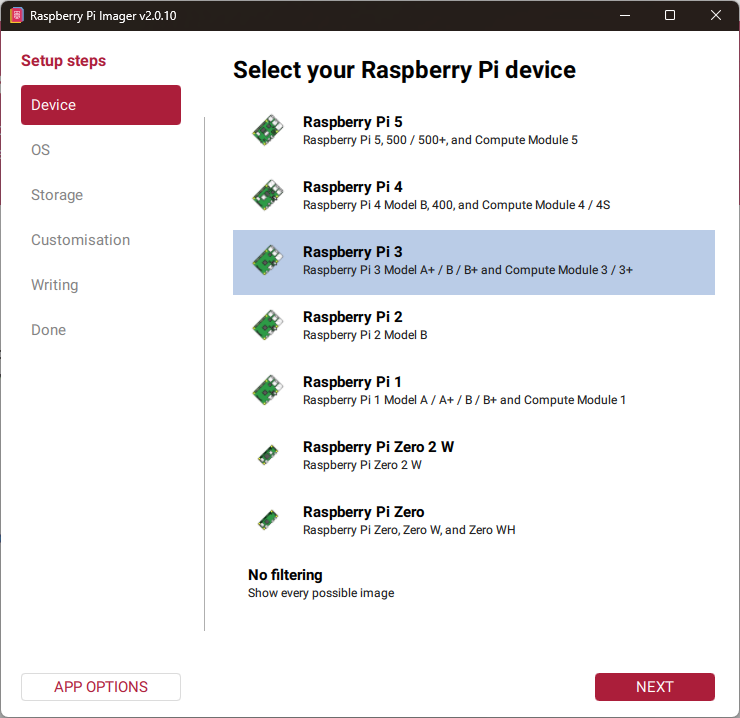
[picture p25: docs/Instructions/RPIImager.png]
Selecting Raspberry Pi 3 in Raspberry Pi Imager
    <td align="center"><br/><strong>1. Select the device</strong></td>
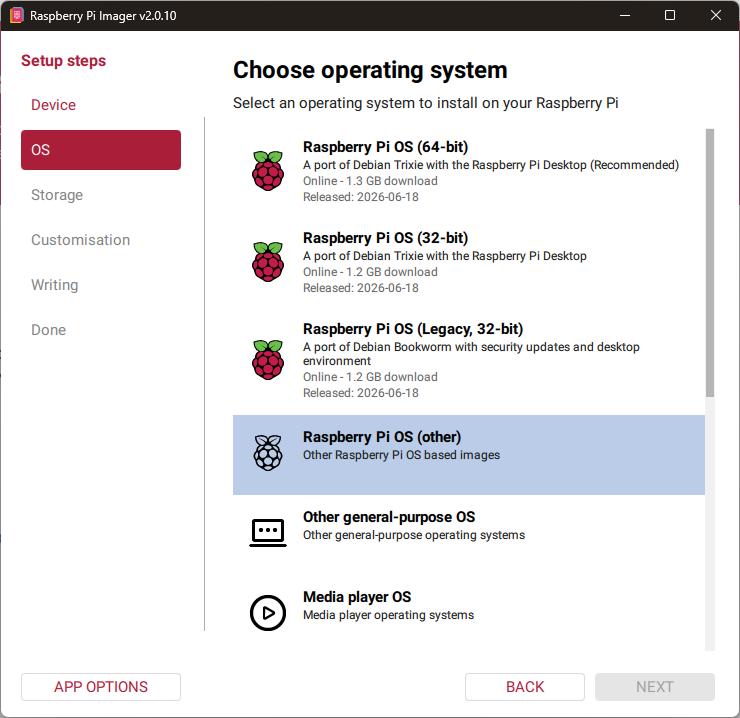
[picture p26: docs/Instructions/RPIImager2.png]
Selecting Raspberry Pi OS other in Raspberry Pi Imager
    <td align="center"><br/><strong>2. Open other OS options</strong></td>
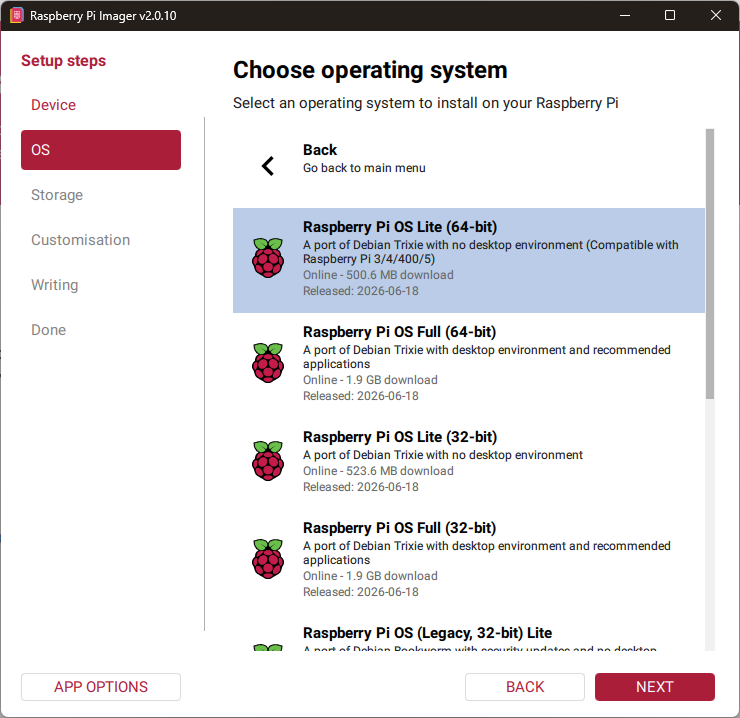
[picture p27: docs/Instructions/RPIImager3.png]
Selecting Raspberry Pi OS Lite in Raspberry Pi Imager
    <td align="center"><br/><strong>3. Select Raspberry Pi OS Lite</strong></td>
  </tr>
</table>

### Imager Customisation

Raspberry Pi Imager can configure the following before the Pi's first boot:

| Setting | Recommendation |
|---|---|
| **Hostname** | Use `mementoframe` to make the Pi available as `mementoframe.local`. A different hostname also works, but use `<your-hostname>.local` when connecting. |
| **Username and password** | Create the account that you will use to sign in and run the installer. |
| **Wi-Fi** | Enter the network name, password, and country if the frame should join Wi-Fi on its first boot. You can also leave this unset and configure Wi-Fi later through MementoFrame AP mode. |
| **Locale and timezone** | Select the values appropriate for the frame's location. |
| **SSH** | **Enable SSH.** Use password authentication or add an SSH public key. |

SSH is required for a peripheral-free installation. After writing the card, insert it into the Pi, power it on, wait for it to join the network, and connect from another computer:

```bash
ssh <username>@mementoframe.local
```

Replace `<username>` with the account created in Raspberry Pi Imager. If you selected another hostname, replace `mementoframe.local` as well. Once connected, run the automatic installation commands in the next section.

### 32-bit and 64-bit Trixie

MementoFrame supports Raspberry Pi OS Lite Trixie in both **32-bit** and **64-bit** versions.

- **64-bit Trixie** can use the full KMS graphics driver.
- **32-bit Trixie** uses the FKMS compatibility driver for this display setup.

Full KMS display behavior is still being tested. Two frames with slightly different revisions of the same display controller PCB produced different results, so FKMS may remain the safer option if the display is blank or unstable.

---

## Automatic Installation (Recommended)

On a fresh Raspberry Pi OS Lite installation, open a terminal and run:

```bash
cd ~
curl -fL https://github.com/MrBroccoliJP/MementoFrame/releases/latest/download/install.sh -o install.sh
sudo bash install.sh
```

This downloads the latest stable MementoFrame release, prepares the Raspberry Pi, and installs the required software. The Pi reboots automatically when the installation finishes.

> **Next:** after the frame restarts, continue with [Post-Install Configuration](#post-install-configuration).

Need a different release, repository, or development checkout? See [Automatic Installation Options and Technical Reference](#automatic-installation-options-and-technical-reference). If the installer cannot complete, use the [manual installation](#manual-installation-advanced).

---

## Post-Install Configuration

After the Pi reboots, open the MementoFrame configuration dashboard using the address that matches the frame's connection:

| Connection | Dashboard address |
|---|---|
| Connected to the frame's `MementoFrame` setup hotspot | `http://192.168.4.1:5000` |
| Frame already connected to your Wi-Fi | `http://mementoframe.local:5000` or `http://<frame-ip>:5000` |

The network address is available immediately only when Wi-Fi credentials were added through Raspberry Pi Imager or the frame has connected previously. Otherwise, begin with the setup hotspot.

### Finding and Opening the Dashboard

The configuration QR code is normally shown in the system area of the frame's display. It always points to the dashboard at the frame's current IP address and port `5000`. Scan it with a phone connected to the same network as the frame.

The Wi-Fi indicator beside the QR code shows which connection is ready:

| Indicator | Meaning | What to do |
|---|---|---|
| **Green** | The frame is connected to a Wi-Fi network and has internet access. | Connect your phone or computer to that same network, then scan the updated QR code. |
| **Blue** | The frame is in **AP (Access Point) mode**. The frame has created its own local Wi-Fi network because it is not connected to another network. | Connect your phone or computer to the open Wi-Fi network named `MementoFrame`, then scan the QR code or open `http://192.168.4.1:5000`. The dashboard PIN protects the configuration page even though the setup network is open. |

#### Access During Night Mode

The dashboard QR code is always shown while the display is on, except when the scheduled night mode has powered the display off. If the screen is off:

1. Power the display off and on to wake it temporarily. It should remain visible for approximately one minute, allowing the network state and QR code to update.
2. Wait for the Wi-Fi indicator to become **green** for a normal Wi-Fi connection or **blue** for AP mode.
3. Scan the QR code only after the indicator and QR address have updated.

#### Dashboard Security PIN

Opening the configuration dashboard from a new browser or device requires a six-digit PIN. The PIN-entry page causes the frame's display to wake so the code can be read, including during night mode. If the screen does not wake or the PIN does not appear, refresh the PIN-entry page and check the display again. Note: The display takes a few seconds to power on.

The PIN-entry page and the matching code on the frame look like this:

<table>
  <tr>
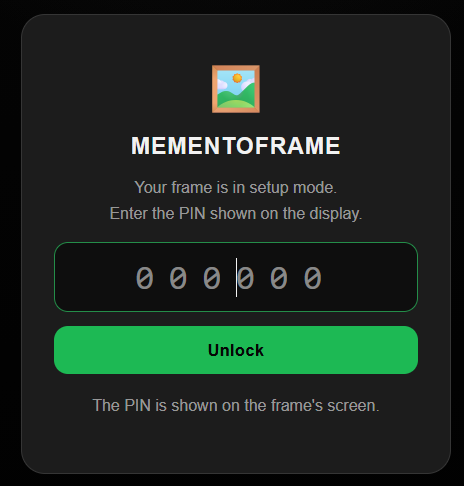
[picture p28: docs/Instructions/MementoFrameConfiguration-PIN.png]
MementoFrame dashboard PIN request
    <td align="center"><br/><strong>Browser PIN request</strong></td>
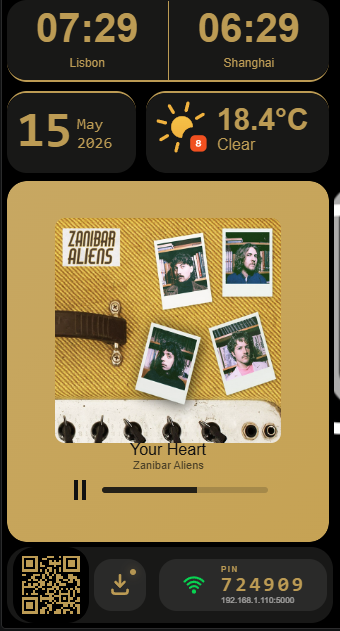
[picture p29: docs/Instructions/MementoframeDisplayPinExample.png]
PIN displayed beside the Wi-Fi indicator on MementoFrame
    <td align="center"><br/><strong>PIN shown on the frame</strong></td>
  </tr>
</table>

Enter the displayed PIN and select **Unlock**. The PIN is temporary and expires after 10 minutes. It disappears from the frame after a successful unlock. Each browser or device has its own locked session; when another browser needs access after the previous PIN was used or expired, MementoFrame generates a new PIN. This prevents a code observed earlier from providing permanent dashboard access.

Configure weather first, then **Spotify app credentials** and the **Spotify user connection** if wanted. New installs default to keyless Open-Meteo; WeatherAPI and Google Weather remain optional alternatives.

This guide uses two kinds of configuration pages:

| Page | Where it runs | Purpose |
|---|---|---|
| **External service dashboard** | A public website such as WeatherAPI.com or Spotify for Developers | Create accounts, API keys, app credentials, redirect URIs, and permitted Spotify users. |
| **MementoFrame dashboard** | On the Raspberry Pi at port `5000` | Give the frame the credentials created by the external services and configure its local behavior. |

The external dashboards do not configure the frame directly. You first create or configure a value on the external website, then copy that value into the MementoFrame dashboard.

### 1. Weather

Under **Weather Configuration**, choose exactly one provider:

| Provider | Setup |
|---|---|
| **Open-Meteo (default)** | Enter city, region, and country; parse coordinates; save. No API key is required. |
| **WeatherAPI.com** | Enter a WeatherAPI key and location. |
| **Google Weather** | Enter a Google Weather API key; enter the location; parse coordinates; save. |

For Open-Meteo or Google Weather, select **Parse Coordinates** before saving. MementoFrame performs one user-triggered OpenStreetMap lookup and stores the coordinates for subsequent forecasts.

#### Optional WeatherAPI setup

The weather setup begins on the external WeatherAPI website and finishes on the frame:

```text
WeatherAPI.com account → API key and response fields → MementoFrame dashboard
```

#### External: WeatherAPI Website

1. Create an account at [WeatherAPI.com](https://www.weatherapi.com/).
2. Open the WeatherAPI dashboard and copy your API key. Keep this browser tab available; the key will be pasted into MementoFrame later.
3. Still in the WeatherAPI dashboard, open **API > API Response Fields** and select the fields listed below. Leaving unused fields disabled reduces the response size while preserving everything MementoFrame displays.

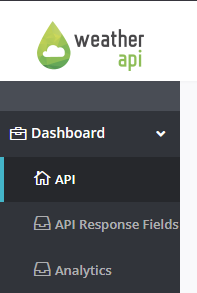
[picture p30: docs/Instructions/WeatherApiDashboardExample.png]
WeatherAPI dashboard API menu


Select these response fields:

| Group | Fields |
|---|---|
| Current Weather | `last_updated`, `temp_c`, `is_day`, `text`, `icon`, `code`, `wind_kph`, `precip_mm`, `humidity`, `feelslike_c`, `uv`, `heatindex_c`, `dewpoint_c` |
| Forecast Day | `date` |
| Forecast Day > Day | `maxtemp_c`, `mintemp_c`, `avgtemp_c`, `totalprecip_mm`, `avghumidity`, `text`, `icon`, `code`, `uv`, `avgwetbulb_c`, `avgwetbulb_f`, `maxwetbulb_c`, `maxwetbulb_f` |
| Forecast Day > Astro | `sunrise`, `sunset`, `moon_phase`, `is_sun_up` |
| Forecast Day > Hour | `time`, `temp_c`, `is_day`, `text`, `icon`, `code`, `wind_kph`, `precip_mm`, `humidity`, `feelslike_c`, `heatindex_c`, `dewpoint_c`, `chance_of_rain`, `uv`, `wetbulb_c`, `wetbulb_f` |

#### Internal: MementoFrame Dashboard

Return to the local MementoFrame dashboard at port `5000`. Under **Weather Configuration**:

1. Paste the API key copied from WeatherAPI.com into **WeatherAPI.com Key**.
2. Enter the weather location as `City,Country`, for example `Aveiro,Portugal`.
3. Select **Save Weather Settings**.

The API key comes from WeatherAPI.com, but the location is configured on MementoFrame itself.

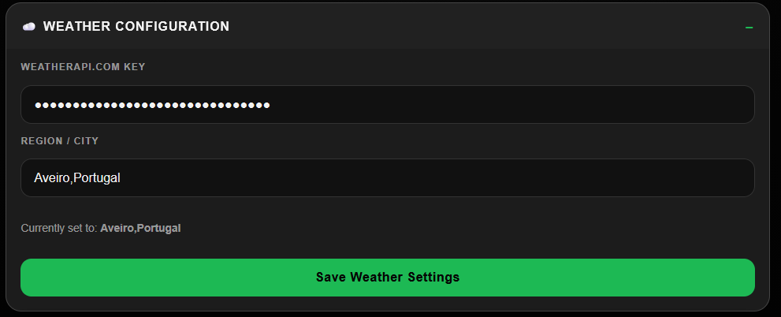
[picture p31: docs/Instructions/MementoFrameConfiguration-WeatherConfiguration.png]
MementoFrame weather configuration


### 2. Spotify App Credentials (Optional)

Spotify playback data requires your own Spotify developer app. This setup also begins on an external website and finishes on the frame:

```text
Spotify Developer Dashboard → Client ID, secret, redirect URI, and users → MementoFrame dashboard
```

#### External: Spotify Developer Dashboard

Create an app in the [Spotify Developer Dashboard](https://developer.spotify.com/dashboard), then open its settings and configure the values shown below.

| Spotify app setting | Value |
|---|---|
| App name | `MementoFrame` (or another name of your choice) |
| App description | `MementoFrame` |
| Redirect URI | `https://httpbin.org/anything` |
| Additional redirect URI shown in the example | `http://127.0.0.1:8080/callback` |
| APIs used | Web API and Web Playback SDK |

The HTTPBin redirect URI is required for the dashboard connection flow. Copy it exactly, including `https://` and `/anything`.

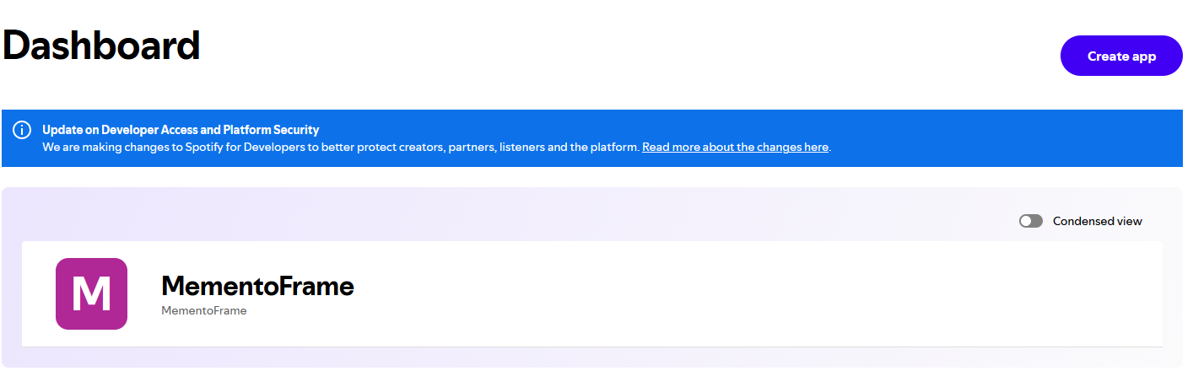
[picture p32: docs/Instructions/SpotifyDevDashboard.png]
Spotify developer dashboard


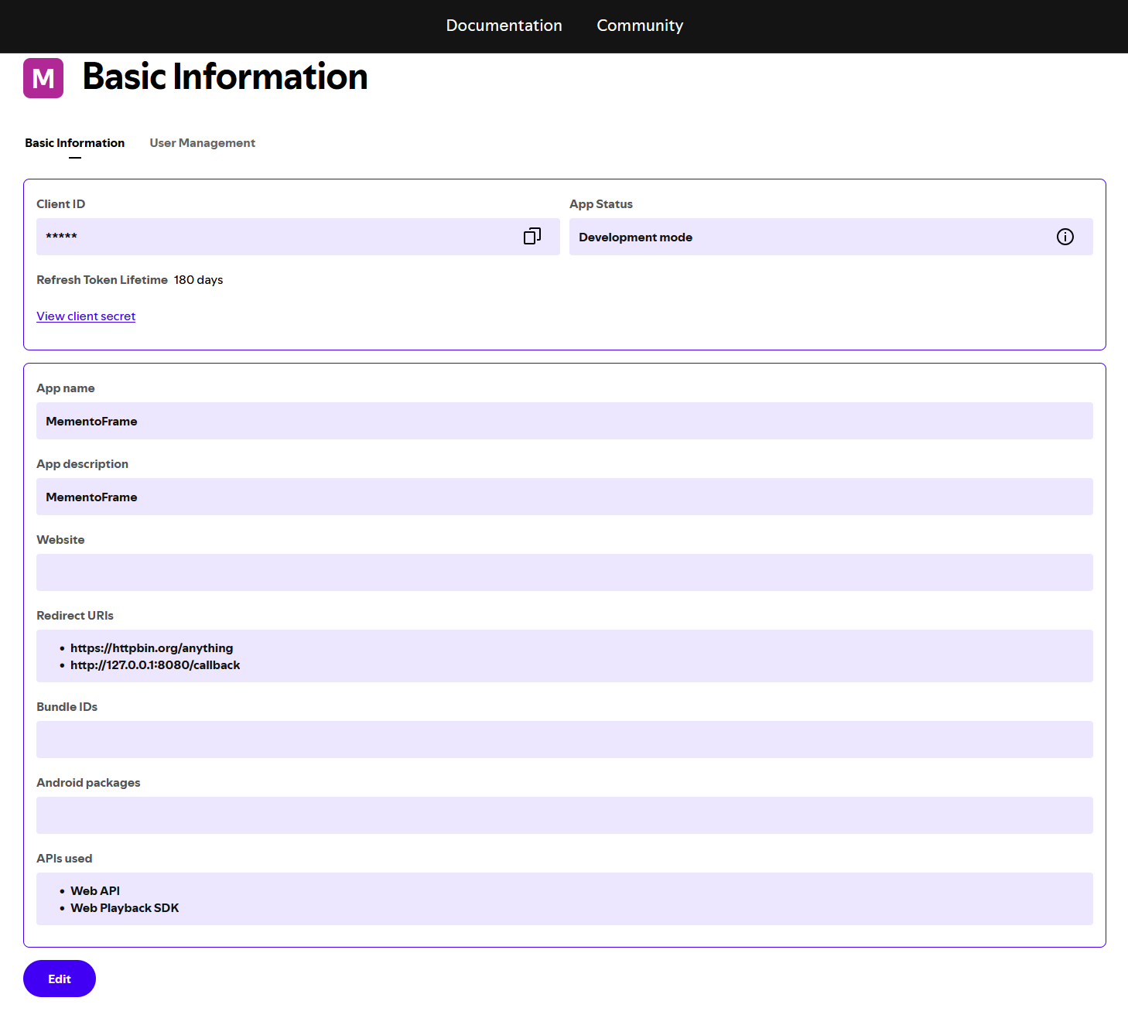
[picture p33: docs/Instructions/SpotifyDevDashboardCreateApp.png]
Spotify app settings


> **Spotify development-mode requirement (2026):** every Spotify account that will connect to MementoFrame must first be explicitly added to the developer app's user allowlist. In February 2026 Spotify changed Development Mode to require a Premium account for the app owner and limit each app to five authorized users. Previously, development apps allowed broader user access. See Spotify's [Development Mode documentation](https://developer.spotify.com/documentation/web-api/concepts/quota-modes) and [February 2026 announcement](https://developer.spotify.com/blog/2026-02-06-update-on-developer-access-and-platform-security).

While still on the external Spotify dashboard, open the app's **User Management** tab. Add each intended user with the full name and email address associated with that user's Spotify account. An unregistered user may appear to sign in, but Spotify will reject that user's API requests.

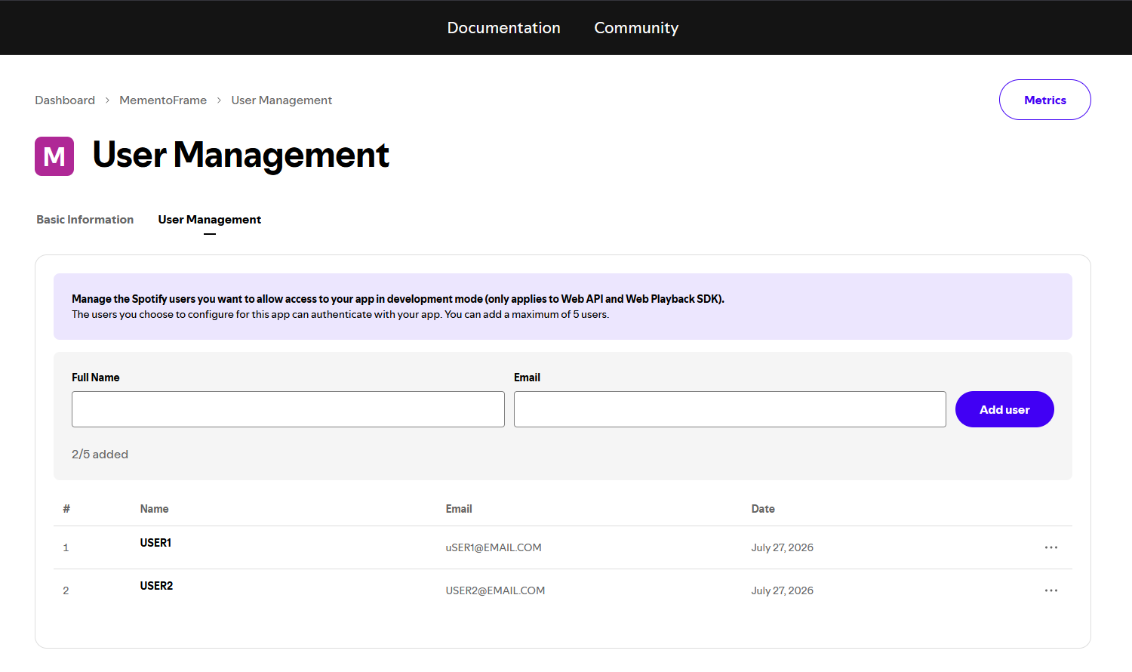
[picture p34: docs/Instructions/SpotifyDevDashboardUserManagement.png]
Spotify user management


Before leaving Spotify's dashboard, copy the app's **Client ID** and reveal and copy its **Client Secret**. Treat the secret like a password.

#### Internal: MementoFrame Dashboard

Return to the local MementoFrame dashboard at port `5000`. Under **Spotify App Settings**:

1. Paste the **Client ID** copied from Spotify.
2. Paste the **Client Secret** copied from Spotify.
3. Enter `https://httpbin.org/anything` as the **Redirect URI**.
4. Select **Save Spotify App Settings**.

The status will say that the credentials are saved but the account is not connected. This is expected until the user authorization in the next section is completed.

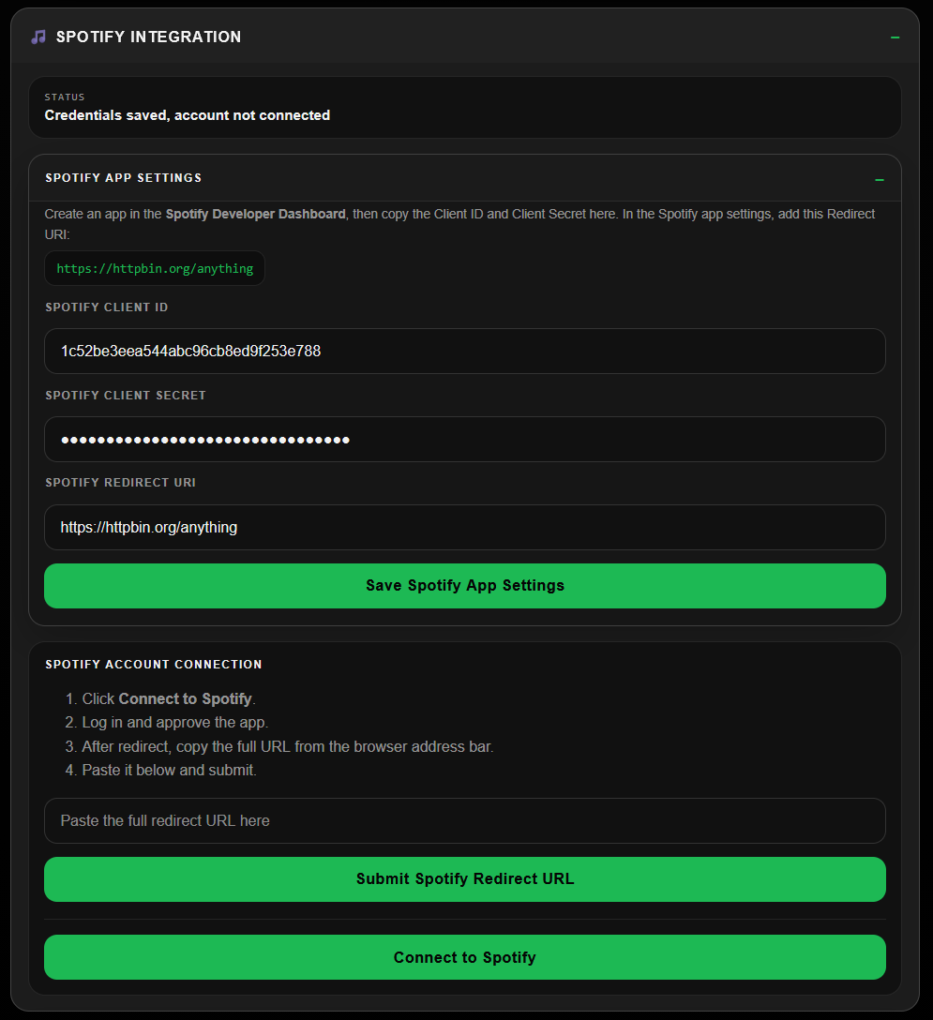
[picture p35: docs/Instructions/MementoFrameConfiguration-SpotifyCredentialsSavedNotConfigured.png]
Spotify credentials saved but not connected


### 3. Connect a Spotify User (Optional)

This stage moves between the internal dashboard, Spotify, HTTPBin, and back to the internal dashboard:

```text
MementoFrame dashboard → Spotify authorization → HTTPBin redirect → MementoFrame dashboard
```

After saving the app credentials and allowlisting the user:

1. **MementoFrame dashboard:** select **Connect to Spotify**.
2. **External Spotify page:** sign in with an allowlisted Spotify account and approve access.
3. **External HTTPBin page:** after Spotify redirects the browser, copy the **entire URL from the browser address bar**, including the `?code=...` query string. Nothing needs to be entered on the HTTPBin page itself.
4. **Return to the MementoFrame dashboard:** switch back to its existing browser tab, use the browser's **Back** button, or open the dashboard again at `http://mementoframe.local:5000` or `http://192.168.4.1:5000` while connected to the setup hotspot. Do not paste the URL into HTTPBin or Spotify.
5. If you returned with the browser's **Back** button, refresh the MementoFrame dashboard before continuing. This ensures the page is ready to receive the authorization response.
6. **MementoFrame dashboard:** paste the copied HTTPBin URL into **Paste full redirect URL here**, then select **Submit Spotify Redirect URL**. The internal dashboard should show **Connected as _user_**.

The authorization code is temporary and can only be used once, so submit the copied URL promptly. If it expires or fails, start again with **Connect to Spotify**.

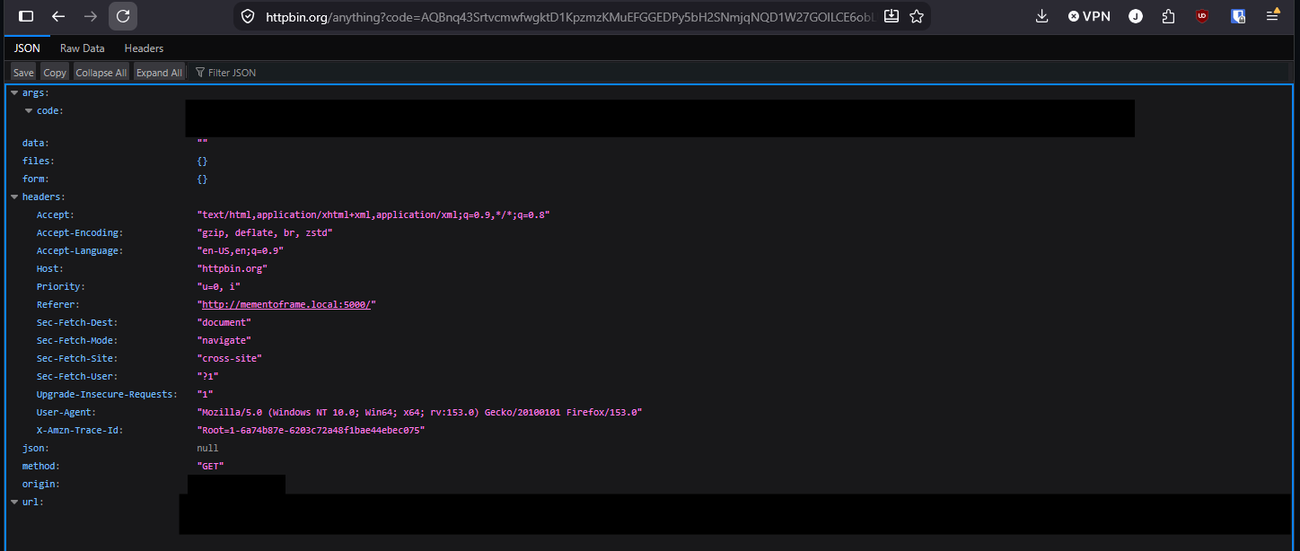
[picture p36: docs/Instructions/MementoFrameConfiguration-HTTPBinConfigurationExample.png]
HTTPBin redirect URL example


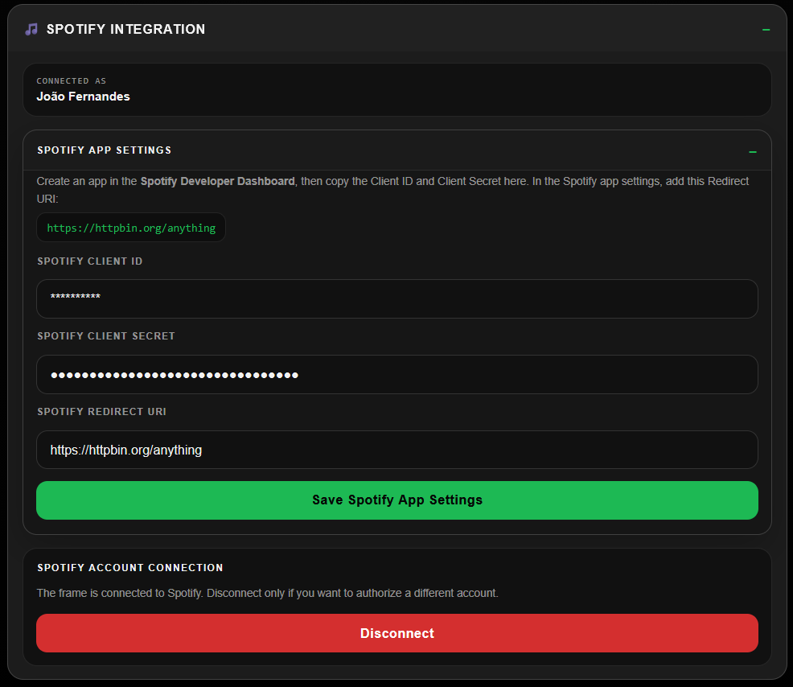
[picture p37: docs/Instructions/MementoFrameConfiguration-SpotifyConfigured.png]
Spotify connected


### 4. Remaining Internal Dashboard Settings

The following settings exist only in the MementoFrame dashboard; they do not require another external service dashboard. Once the integrations are working, configure them to suit the installation.

#### Wi-Fi and Frame Controls

Choose a network, enter its password, and select **Connect**. The controls at the top of the page can reload the display, restart the frame, or turn the screen on.

> **After selecting Connect:** the dashboard will stop responding or refreshing when the frame leaves AP mode and receives a new IP address. This is expected. Connect your phone or computer to the selected Wi-Fi network, wait for the frame's Wi-Fi indicator to turn **green**, and then scan the updated QR code on the display to reopen the dashboard at its new address. If the indicator remains **blue**, the connection was not completed and the frame is still in AP mode; reconnect your device to the `MementoFrame` Wi-Fi network and use `http://192.168.4.1:5000`.

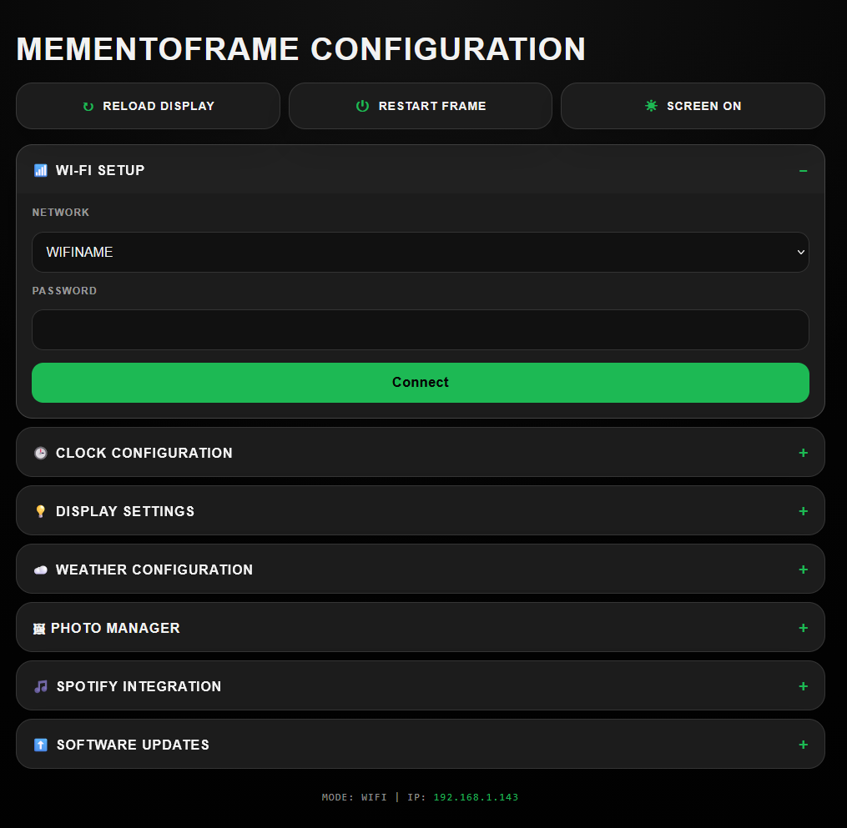
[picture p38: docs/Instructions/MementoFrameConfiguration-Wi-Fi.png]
Wi-Fi and frame controls


#### Clocks

Set the primary clock's timezone and label. A second clock can be enabled with a separate timezone and label.

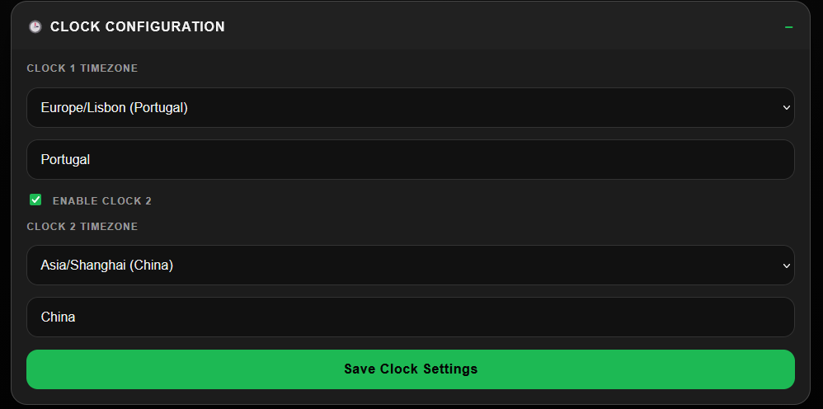
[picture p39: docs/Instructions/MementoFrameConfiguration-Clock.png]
Clock configuration


#### Display and Power Schedule

Set the display brightness and optionally enable an automatic off/on schedule. Save the schedule after changing its times.

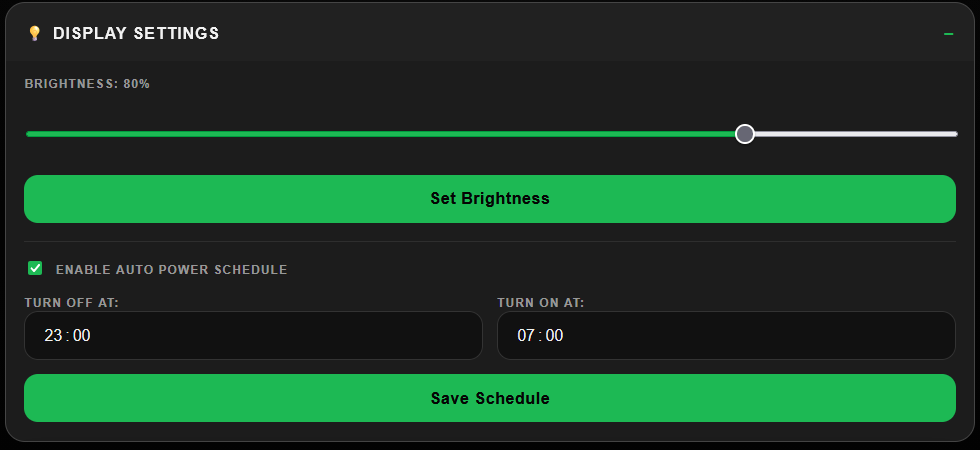
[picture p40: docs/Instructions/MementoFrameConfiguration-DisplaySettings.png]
Display settings


#### Photos

Upload the photos shown by the frame, monitor upload progress, and select existing photos for deletion.

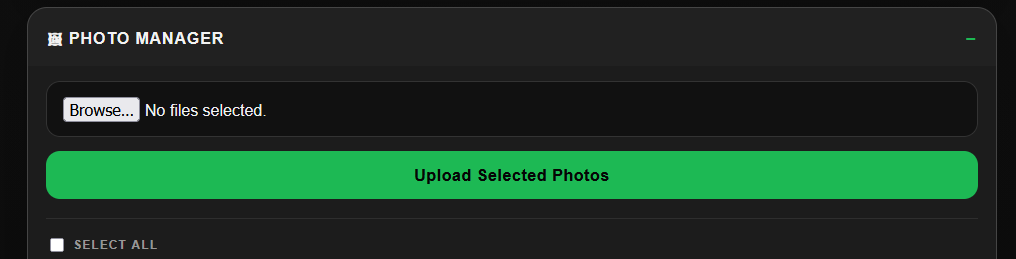
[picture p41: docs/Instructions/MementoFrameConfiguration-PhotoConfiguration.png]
Photo configuration


#### Updates

Choose the update repository and stable or pre-release channel, enable or disable automatic updates, check for a newer release, and install it from the dashboard.

When **Automatically install updates** is enabled, MementoFrame checks for updates hourly but only installs an available update during a one-hour installation window:

- If the automatic display power schedule is enabled, the window begins at the configured **screen-on time**. For example, an on time of `07:00` permits installation between `07:00` and `07:59`.
- If the automatic display power schedule is disabled, the default installation window is `07:00`–`07:59` in the Raspberry Pi's local time.

After successfully installing an automatic update, MementoFrame requests a reboot so the new version can start. The dashboard's **Install Update Now** action does not wait for this scheduled window.

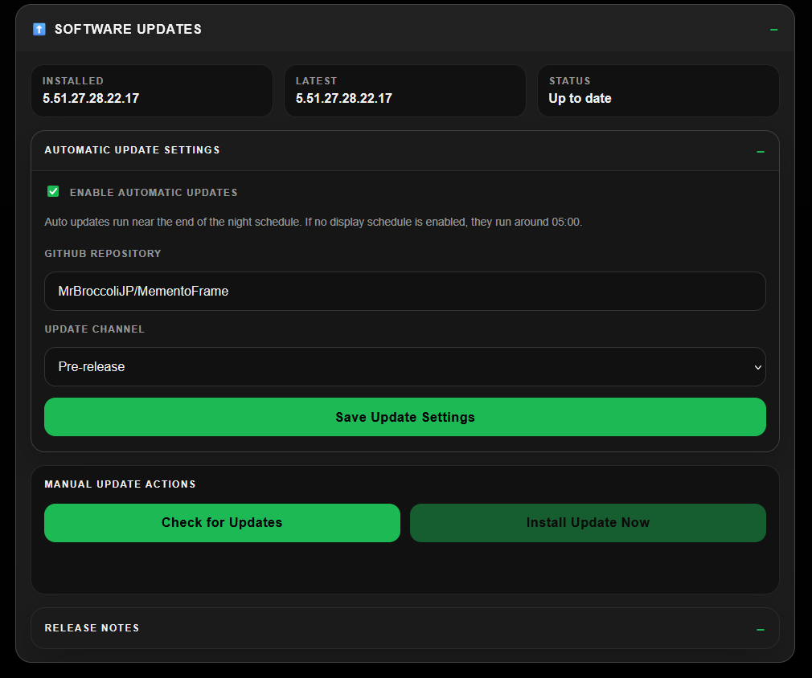
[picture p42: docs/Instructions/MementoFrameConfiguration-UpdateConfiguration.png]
Update configuration


### Advanced `.env` Configuration

The installer runs `updater.py install`, which creates `.env` if it is missing. The dashboard is the recommended place to save WeatherAPI and Spotify settings, but administrators can edit the environment file directly:

```bash
sudo -u mementoframe nano /home/mementoframe/mementoframe/.env
```

```env
SPOTIFY_CLIENT_ID=
SPOTIFY_CLIENT_SECRET=
SPOTIFY_REDIRECT_URI=https://httpbin.org/anything
GITHUB_TOKEN=
MEMENTOFRAME_UPDATE_REPO=MrBroccoliJP/MementoFrame
```

Private GitHub repository updates require `GITHUB_TOKEN`. Never commit `.env` or share the Spotify client secret or WeatherAPI key.

---

## Automatic Installation Options and Technical Reference

This section documents optional installer controls and the system changes made by the recommended installation. Most users do not need these details.

### Tested Hardware

| Component | Tested configuration |
|---|---|
| Raspberry Pi | Raspberry Pi 3B+ |
| Operating system | Raspberry Pi OS Lite 13 (Trixie), 32-bit and 64-bit |
| Python | Raspberry Pi OS system Python, tested with Python 3.13 |
| Display | GeekPi 7-inch HDMI display, 1024×600 |

### Software and Services Used

- NetworkManager and `nmcli` for Wi-Fi and AP mode
- Flask services for the configuration dashboard and display API
- Chromium in kiosk mode
- GPIO controls for display power and brightness
- I²C and the Raspberry Pi RTC overlay for the DS3231 clock
- `updater.py` for installation and GitHub Release updates
- Separate systemd services for the configuration, display, network, kiosk, updater, and post-reboot checks
- Pillow and system WebP libraries for photos and thumbnails

### Installer Options

Install a specific release tag:

```bash
sudo INSTALL_TAG=v5.51.27.28.22.17 bash install.sh
```

Install the newest non-draft pre-release or release instead of only the latest stable release:

```bash
sudo INSTALL_CHANNEL=pre-release bash install.sh
```

Skip the final reboot while developing or testing installer changes:

```bash
sudo SKIP_REBOOT=1 bash install.sh
```

Install from a fork or another repository:

```bash
sudo INSTALL_REPO=owner/repository bash install.sh
```

Use a local checkout instead of downloading a release:

```bash
sudo SRC_DIR="$(pwd)" bash mementoframe/install.sh
```

`SRC_DIR` must point to the repository root containing the inner `mementoframe/` application folder. This override is intended for development.

### What the Installer Does

`install.sh`:

1. Requires root/sudo and creates the `mementoframe` user when needed.
2. Adds the user to the required `video`, `input`, `gpio`, and `netdev` hardware groups.
3. Stops an earlier MementoFrame installation before changing network settings.
4. Installs Chromium, NetworkManager, X/Openbox, GPIO, WebP, RTC, and Python dependencies.
5. Enables NetworkManager, handles conflicting `dhcpcd`, unblocks Wi-Fi, and enables its radio.
6. Configures HDMI, quiet boot, X permissions, GPIO screen enable, and the DS3231 RTC.
7. Downloads the selected GitHub Release to `/home/mementoframe/mementoframe` and runs `updater.py install`.
8. Enables automatic updates using the selected repository and release channel.
9. Creates the kiosk launcher, split systemd services, and limited sudo permissions.
10. Enables the services and reboots unless `SKIP_REBOOT=1` is set.

### Runtime Files

| File | Purpose |
|---|---|
| `config_portal_service.py` | Configuration dashboard on port `5000`. |
| `display_service.py` | Local display/frontend API on port `5001`. |
| `network_manager_service.py` | NetworkManager Wi-Fi/AP fallback watchdog. |
| `updater.py` | Installer, update, autoupdate, and repair helper. |
| `version_info.py` | Composite release/component version metadata. |
| `requirements.txt` | Python dependencies. |
| `config.json` | User configuration. |
| `.env` | Local secrets and optional GitHub token. |
| `resources/userdata/` | Persistent photos, thumbnails, cache, and generated files. |
| `runtime/` | Runtime state, including update state and temporary PIN data. |

### Directories

| Path | Purpose |
|---|---|
| `/home/mementoframe/mementoframe` | Runtime application root. |
| `/tmp/mementoframe-install-src` | Temporary extracted release source. |
| `/home/mementoframe/mementoframe/resources/userdata` | Persistent user data preserved during updates. |
| `/home/mementoframe/mementoframe/runtime` | Runtime state preserved during updates. |
| `/home/mementoframe/mementoframe/.env` | Local secrets preserved during updates. |
| `/home/mementoframe/mementoframe_backups` | Update backups. |

### Boot Display Configuration

The installer creates timestamped backups before editing the existing configuration:

```text
/boot/firmware/config.txt.mementoframe.bak.YYYYMMDD-HHMMSS
/boot/firmware/cmdline.txt.mementoframe.bak.YYYYMMDD-HHMMSS
/etc/X11/Xwrapper.config.mementoframe.bak.YYYYMMDD-HHMMSS
```

It preserves unrelated Raspberry Pi settings and ensures `dtoverlay=vc4-fkms-v3d` exists globally. Under `[all]`, it configures the DS3231 RTC, tested 1024×600 HDMI display, and GPIO screen-enable pin:

```ini
[all]
dtparam=i2c_arm=on
dtoverlay=i2c-rtc,ds3231
enable_uart=1
disable_splash=1
avoid_warnings=1
gpu_mem=185
gpio=26=op,dh
hdmi_force_hotplug=1
hdmi_group=2
hdmi_mode=87
hdmi_cvt=1024 600 60 6 0 0 0
config_hdmi_boost=7
```

The DS3231 normally becomes `/dev/rtc0` after reboot. `util-linux-extra` supplies the `hwclock` userspace utility.

The installer keeps `/boot/firmware/cmdline.txt` on one line and ensures these quiet-boot values:

```text
console=tty3 quiet splash loglevel=1 logo.nologo vt.global_cursor_default=0 consoleblank=0
```

It preserves `fsck.repair=yes`, does not add the less-safe `fsck.mode=skip`, writes the following X wrapper configuration, and masks the tty1 login prompt:

```ini
allowed_users=anybody
needs_root_rights=yes
```

```bash
systemctl disable --now getty@tty1.service
systemctl mask getty@tty1.service
```

---

## Manual Installation (Advanced)

Use this path when the automatic installer cannot complete or when you need to perform and diagnose each stage yourself. The automatic and manual methods are alternatives; do not run both for a normal installation.

Install the operating-system dependencies and create the dedicated runtime user:

```bash
sudo apt update
sudo apt install -y \
  python3 python3-pip python3-venv git \
  network-manager wireless-tools iw iproute2 rfkill curl ca-certificates \
  chromium unclutter xserver-xorg xinit openbox x11-xserver-utils \
  libjpeg-dev zlib1g-dev libwebp-dev webp util-linux-extra python3-rpi.gpio

sudo adduser --disabled-password --gecos "MementoFrame" mementoframe || true
sudo usermod -aG video,input,gpio,netdev mementoframe
```

Copy the repository's inner `mementoframe/` directory to the runtime location, then initialize it:

```bash
sudo mkdir -p /home/mementoframe/mementoframe
sudo cp -a /path/to/release-or-checkout/mementoframe/. /home/mementoframe/mementoframe/
sudo chown -R mementoframe:mementoframe /home/mementoframe/mementoframe

cd /home/mementoframe/mementoframe
sudo -u mementoframe python3 updater.py install
```

Replace `/path/to/release-or-checkout` with the extracted release or checkout root. The source must contain the inner `mementoframe/` application folder.

Complete the same system integration performed by `install.sh`:

1. Apply the settings in [Boot Display Configuration](#boot-display-configuration), preserving unrelated Raspberry Pi settings.
2. Configure NetworkManager and disable conflicting `dhcpcd` management if it is present.
3. Create the five units listed under [Services](#services).
4. Add the limited permissions described in [Update/Reboot/Wi-Fi Permissions](#updaterebootwi-fi-permissions).
5. Enable the services and reboot.

For the RTC, ensure these directives are present under `[all]` in `/boot/firmware/config.txt`:

```ini
[all]
dtparam=i2c_arm=on
dtoverlay=i2c-rtc,ds3231
```

After rebooting, confirm that Raspberry Pi OS created the RTC device:

```bash
ls -l /dev/rtc*
sudo hwclock --show
```

If the automatic installer failed only because packages were missing, install the dependencies above and rerun `sudo bash install.sh` instead of continuing with the fully manual path.

---

## Services

### `mementoframe-config.service`

Runs the admin/configuration portal.

```text
/etc/systemd/system/mementoframe-config.service
```

Important values:

```ini
User=mementoframe
WorkingDirectory=/home/mementoframe/mementoframe
ExecStart=/home/mementoframe/mementoframe/venv/bin/python3 /home/mementoframe/mementoframe/config_portal_service.py
```

Port:

```text
5000
```

### `mementoframe-display.service`

Runs the local display/frontend API.

```text
/etc/systemd/system/mementoframe-display.service
```

Important values:

```ini
User=mementoframe
WorkingDirectory=/home/mementoframe/mementoframe
ExecStart=/home/mementoframe/mementoframe/venv/bin/python3 /home/mementoframe/mementoframe/display_service.py
```

Port:

```text
5001
```

### `mementoframe-network.service`

Runs the NetworkManager Wi-Fi/AP fallback watchdog.

```text
/etc/systemd/system/mementoframe-network.service
```

Important values:

```ini
User=root
WorkingDirectory=/home/mementoframe/mementoframe
ExecStart=/home/mementoframe/mementoframe/venv/bin/python3 /home/mementoframe/mementoframe/network_manager_service.py
```

This service runs as root so the existing NetworkManager commands can manage AP/client mode reliably.

### `mementoframe-kiosk.service`

Runs Chromium in kiosk mode.

```text
/etc/systemd/system/mementoframe-kiosk.service
```

Important values:

```ini
User=mementoframe
Environment=DISPLAY=:0
ExecStart=/usr/bin/startx /usr/local/bin/mementoframe-kiosk.sh -- :0
After=mementoframe-display.service
Requires=mementoframe-display.service
```

The kiosk launcher disables X screen saver/DPMS every time X starts. This prevents HDMI from going to “No Signal” after the default 10-minute X timeout. It also hides the cursor with `unclutter`, sets the X root background black, stores Chromium cache in `/dev/shm`, and uses GPU/compositing flags for smoother image fades.

### `mementoframe-updater.service`

Runs automatic update checks/install attempts when triggered by the timer.

```text
/etc/systemd/system/mementoframe-updater.service
```

Important values:

```ini
User=mementoframe
WorkingDirectory=/home/mementoframe/mementoframe
ExecStart=/home/mementoframe/mementoframe/venv/bin/python3 /home/mementoframe/mementoframe/updater.py autoupdate
```

### `mementoframe-updater.timer`

Runs the updater service periodically.

```text
/etc/systemd/system/mementoframe-updater.timer
```

Important values:

```ini
OnBootSec=2min
OnUnitActiveSec=1h
Persistent=true
Unit=mementoframe-updater.service
```

---

## Service Commands

Restart everything:

```bash
sudo systemctl restart mementoframe-network.service
sudo systemctl restart mementoframe-config.service
sudo systemctl restart mementoframe-display.service
sudo systemctl restart mementoframe-kiosk.service
```

Check status:

```bash
systemctl status mementoframe-config.service
systemctl status mementoframe-display.service
systemctl status mementoframe-network.service
systemctl status mementoframe-kiosk.service
systemctl status mementoframe-updater.service
systemctl status mementoframe-updater.timer
```

Useful logs:

```bash
journalctl -u mementoframe-config.service -f
journalctl -u mementoframe-display.service -f
journalctl -u mementoframe-network.service -f
journalctl -u mementoframe-kiosk.service -f
journalctl -u mementoframe-updater.service -n 80 --no-pager
```

---

## Update/Reboot/Wi-Fi Permissions

The installer creates:

```text
/etc/sudoers.d/mementoframe-updater
```

With limited permissions for the app user:

```sudoers
mementoframe ALL=(root) NOPASSWD: \
  /usr/bin/systemctl restart mementoframe-config.service, \
  /usr/bin/systemctl restart mementoframe-display.service, \
  /usr/bin/systemctl restart mementoframe-network.service, \
  /usr/bin/systemctl restart mementoframe-kiosk.service, \
  /usr/bin/systemctl restart NetworkManager, \
  /home/mementoframe/mementoframe/repair_services.sh, \
  /usr/bin/systemctl stop hostapd, \
  /usr/bin/systemctl stop dnsmasq, \
  /usr/bin/nmcli, \
  /usr/sbin/reboot, \
  /sbin/reboot, \
  /usr/bin/reboot
```

The `mementoframe` user is not granted unrestricted root access.

---

## Verify Install

```bash
curl http://127.0.0.1:5000/health
curl http://127.0.0.1:5001/health
curl http://127.0.0.1:5000/versions
curl http://127.0.0.1:5001/versions
```

Then check services:

```bash
systemctl status mementoframe-config.service
systemctl status mementoframe-display.service
systemctl status mementoframe-network.service
systemctl status mementoframe-kiosk.service
```

Check Wi-Fi radio state:

```bash
nmcli radio wifi
nmcli device status
```

After the kiosk starts, verify X screen blanking is disabled:

```bash
DISPLAY=:0 xset q
```

Expected values include `timeout: 0` under Screen Saver and `DPMS is Disabled`.

---

## Updating

Updates are handled by `updater.py` and GitHub Releases.

Each GitHub Release should include `install.sh` as a release asset so first-time users can install the latest tested release without cloning the repository.

GitHub release tags should use the composite version from `version_info.py`:

```text
v<release>.<frontend>.<config>.<display>.<network>.<updater>
```

Example:

```text
v5.51.27.28.22.17
```

Manual terminal update:

```bash
cd /home/mementoframe/mementoframe
python3 updater.py check
python3 updater.py update
```

Test update without reboot:

```bash
python3 updater.py update --no-reboot
```

The updater checks hourly. If auto-updates are enabled, an available update is installed during the one-hour window beginning at the configured display **on time**, which is the end of the overnight/off period. If no automatic display schedule is enabled, the installation window defaults to `07:00`–`07:59` in the Raspberry Pi's local time.

---

## Development/Release Notes on Windows

If editing on Windows, Git may not preserve Unix executable bits automatically. Mark shell scripts executable in Git before releasing:

```bash
git update-index --chmod=+x install.sh
# or, if the installer lives inside the inner app folder in your repo:
# git update-index --chmod=+x mementoframe/install.sh
```
---

## License

Creative Commons Attribution-NonCommercial 4.0 International

[http://creativecommons.org/licenses/by-nc/4.0/](http://creativecommons.org/licenses/by-nc/4.0/)

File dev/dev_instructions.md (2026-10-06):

# MementoFrame Mock Apps

The `dev` folder provides a desktop development environment for the
MementoFrame frontend and configuration portal. It mirrors the production
routes closely enough to develop UI changes and test application states without
a Raspberry Pi, GPIO hardware, systemd, NetworkManager, or a connected display.

## Requirements

- Python 3.11 or later
- The MementoFrame repository
- A browser
- Internet access only when testing real Spotify, WeatherAPI, or GitHub calls

The mock services use these Python packages:

- Flask
- Flask-CORS
- Pillow
- python-dotenv
- Requests
- Spotipy
- Werkzeug

Create a virtual environment from the repository root.

### Windows PowerShell

```powershell
py -m venv .venv
.\.venv\Scripts\Activate.ps1
python -m pip install --upgrade pip
python -m pip install Flask flask-cors Pillow python-dotenv requests spotipy Werkzeug
```

### Linux or macOS

```bash
python3 -m venv .venv
source .venv/bin/activate
python -m pip install --upgrade pip
python -m pip install Flask flask-cors Pillow python-dotenv requests spotipy Werkzeug
```

The mock environment does not import `RPi.GPIO`, so that package is not
required for desktop development.

## Running the Mocks

Start both services from the repository root:

```bash
python dev/run_mocks.py
```

On Windows, this is also valid:

```powershell
py dev/run_mocks.py
```

The launcher starts both processes and prints their URLs:

| Interface | URL | Purpose |
|---|---|---|
| Configuration portal | `http://localhost:5000` | Develop and test the admin/configuration UI. |
| Display UI | `http://localhost:5001` | Render the kiosk frontend against mock APIs. |
| Mock controls | `http://localhost:5001/mock` | Change simulated device, weather, Spotify, time, PIN, and update state. |
| Forced-time JSON | `http://localhost:5001/mock/time.json` | Inspect the active browser-time override. |

Press `Ctrl+C` in the terminal to stop both services.

If port 5000 or 5001 is already in use, stop the conflicting process before
starting the mocks.

## Mock Components

| File | Role |
|---|---|
| `dev/run_mocks.py` | Starts and stops both mock web services. |
| `dev/mock_config_portal_service.py` | Endpoint-compatible configuration portal on port 5000. |
| `dev/mock_display_service.py` | Display frontend, widget APIs, and mock control panel on port 5001. |
| `dev/mock_shared.py` | Shared state, payload builders, photo helpers, external-service helpers, and runtime paths. |
| `dev/mock_updater.py` | Safe command-line interface for testing updater states. |
| `dev/runtime/` | Mock-only state, PIN, update state, and Spotify cache. Created automatically. |

## What Can Be Tested

The control panel at `http://localhost:5001/mock` supports:

- Client Wi-Fi, fallback AP, and unknown network modes [simulated only, no network control on the host]
- Simulated IP addresses, SSIDs, and known networks
- Screen on/off state [simulated, logs available on the frontend console]
- Configuration PIN creation and expiration
- Fixed or ticking browser time
- Mock Spotify playback, tracks, connection state, and progress
- Mock weather, forecast, astronomy, and alert data
- No-weather and current-weather-only layouts
- Photo upload, deletion, ordering, and reload behavior
- Server-Sent Events frontend reloads
- Available-update, installing, and automatic-update UI states

Most frontend work can use the built-in mock Spotify and weather data without
API credentials.

## Mock State and Project Data

Mock-only runtime state is written to:

```text
dev/runtime/
├── mock_state.json
├── update_state.json
├── config_portal_pin.json
└── .cache_spotify
```

The mock applications intentionally render the real files under
`mementoframe/templates`, `mementoframe/static`, and
`mementoframe/resources/assets`. Changes to those frontend files are visible
after refreshing the browser.

The configuration portal also uses the project's real local development data:

- `mementoframe/config.json`
- `mementoframe/.env`, when present
- `mementoframe/resources/userdata/Photos/`
- `mementoframe/resources/userdata/cache/`

As a result, configuration edits, credential changes, and photo operations made
through the mock portal can modify those local files. Use development data and
do not enter production secrets into a shared working tree.

## Testing Time-Dependent UI

Open the mock controls and configure the Forced time section. The display
service injects `/mock/time-override.js` into the frame page before the
frontend runs.

You can set:

- A fixed ISO datetime
- Whether simulated time continues ticking
- Whether the override is enabled

This is useful for testing clock layouts, date changes, schedules, nighttime
styles, and other time-dependent behavior without changing the computer clock.

## Testing Spotify and Weather

Both integrations support `mock` and `real` data sources.

Mock mode is the default and requires no credentials. Use the control panel to
change tracks, playback state, weather conditions, day/night state, forecasts,
and alerts.

Real integration testing may use values stored in `mementoframe/.env`:

```dotenv
SPOTIFY_CLIENT_ID=
SPOTIFY_CLIENT_SECRET=
SPOTIFY_REDIRECT_URI=
WEATHER_API_KEY=
```

The weather API key can also be saved through the mock configuration portal.
Real integrations require network access and are no longer fully isolated
tests.

## Testing Layouts from the Browser Console

Use `testLayout(spotify, calendar, forecast)` in the frame page's browser
console to lock a specific widget combination for visual testing. While the
test layout is locked, the normal one-second layout rotation will not override
it.

```javascript
testLayout('hidden', 'hidden', 'f5dBig');   // Expanded five-day forecast
testLayout('hidden', 'hidden', 'f5hBig');   // Expanded five-hour forecast
testLayout('hidden', 'hidden', '5h-icons'); // Compact five-hour forecast
```

The canonical forecast names are `hidden`, `5h-icons`, `5h-big`, and `5d-big`.
For convenience, the console helper also accepts `f5hIcons`, `f5hBig`, and
`f5dBig`. Spotify accepts `hidden`, `shrunk`, or `big`; calendar accepts
`hidden`, `month`, or `week`.

Resume normal automatic layout rotation when testing is complete:

```javascript
clearTestLayout();
```

## Testing Updates Safely

The mock updater simulates update states but never installs project files or
reboots the computer.

Use the mock control panel for UI testing, or run:

```bash
python dev/mock_updater.py status
python dev/mock_updater.py pending-on
python dev/mock_updater.py pending-off
python dev/mock_updater.py check
python dev/mock_updater.py install
python dev/mock_updater.py autoupdate
python dev/mock_updater.py diagnose
```

A simulated update first spends 3 seconds downloading with no display overlay.
The overlay appears only when the 90-second installation begins, then remains
through the simulated reboot and post-reboot verification. This matches the
production updater lifecycle. Change the download or install duration for a
test session with:

```bash
MEMENTOFRAME_MOCK_DOWNLOAD_SECONDS=1 MEMENTOFRAME_MOCK_INSTALL_SECONDS=10 python dev/run_mocks.py
```

In PowerShell:

```powershell
$env:MEMENTOFRAME_MOCK_DOWNLOAD_SECONDS = "1"
$env:MEMENTOFRAME_MOCK_INSTALL_SECONDS = "10"
python dev/run_mocks.py
```

The simulated reboot and verification phases default to 3 and 5 seconds. They
can be adjusted with `MEMENTOFRAME_MOCK_REBOOT_SECONDS` and
`MEMENTOFRAME_MOCK_VERIFY_SECONDS` when testing those transitions.

## Troubleshooting

### A dependency is missing

Activate the virtual environment and reinstall the mock dependencies:

```bash
python -m pip install Flask flask-cors Pillow python-dotenv requests spotipy Werkzeug
```

### The UI does not reflect frontend changes

Refresh the display page. For state or photo changes, use the portal's reload
action or restart the mock launcher.

### Mock state needs to be reset

Stop the services, then remove only the generated files inside `dev/runtime`.
They will be recreated with defaults the next time the mocks start.

### A service exits immediately

Run it directly to see its complete error:

```bash
python dev/mock_config_portal_service.py
python dev/mock_display_service.py
```

Run individual services from the repository root so the real
`mementoframe` templates and assets can be resolved correctly.

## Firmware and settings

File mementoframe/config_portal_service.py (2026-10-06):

#!/usr/bin/env python3
# MementoFrame - Raspberry Pi Smart Photo Frame
# Copyright (c) 2026 João Fernandes
#
# This work is licensed under the Creative Commons Attribution-NonCommercial
# 4.0 International License. To view a copy of this license, visit:
# http://creativecommons.org/licenses/by-nc/4.0/

"""
app.py

Brief:
    Flask configuration portal for MementoFrame.

Endpoints:
    GET|POST /                         - Dashboard and Wi-Fi connection form.
    GET      /assets/<filename>        - Serve static project assets.
    GET      /userdata/<filename>      - Serve persistent user data files.
    GET      /resources/Photos/full/<filename>   - Serve full-size uploaded photos.
    GET      /resources/Photos/thumbs/<filename> - Serve generated photo thumbnails.
    POST     /upload                   - Queue uploaded photos and process WebP images in background.
    GET      /upload/status            - Return current background photo-processing state.
    POST     /delete_selected_photos   - Delete selected uploaded photos.
    POST     /test_brightness          - Start a background brightness test.
    POST     /save_clock_settings      - Save dashboard clock settings.
    POST     /save_appearance_settings - Save theme and weather icon settings.
    POST     /save_display_settings    - Save brightness settings.
    POST     /save_auto_power          - Save automatic screen power schedule.
    POST     /save_weather_api         - Save weather provider, credentials, and location.
    POST     /weather/geocode          - Resolve a weather location to coordinates.
    POST     /weather/refresh          - Ask the display service for fresh weather data.
    GET      /versions                 - Return installed component versions.
    GET      /spotify/connect          - Begin Spotify OAuth authorization.
    POST     /spotify/manual           - Complete Spotify OAuth using pasted callback URL.
    POST     /spotify/disconnect       - Remove cached Spotify credentials.
    GET      /config-portal-pin        - Show PIN unlock page for AP configuration mode.
    POST     /config-portal-pin        - Validate submitted configuration portal PIN.

Flow chart:

    ┌────────────────────────┐
    │ Request enters Flask   │
    └──────┬─────────────────┘
           │
           ├── PIN locked ─────► Wake screen → create/read PIN → show PIN page
           │
           └── PIN unlocked ───► Dashboard/routes manage Wi-Fi, photos, settings,
                                  Spotify auth, brightness, and config persistence
"""
from flask import Flask, request, render_template, redirect, url_for, jsonify, send_from_directory, session
import subprocess, os, json, socket, threading, time, uuid, shlex, secrets, sys, tempfile
import requests
from pathlib import Path
from werkzeug.utils import secure_filename
from dotenv import load_dotenv
from PIL import Image, ImageOps
import RPi.GPIO as GPIO
import spotipy
import requests
from spotipy.oauth2 import SpotifyOAuth
from updater import (
    UPDATER_LOCK_FILE,
    can_start_background_update,
    interprocess_file_lock,
    state_file_lock,
)
from version_info import GLOBAL_APP_VERSION, VERSION_INFO

# =============================================================================
# Environment and Flask initialization
# =============================================================================
ENV_FILE = Path(".env")


def read_env_values():
    """Read simple KEY=value pairs from .env without exposing unrelated parsing complexity."""
    values = {}
    if not ENV_FILE.exists():
        return values

    try:
        for raw in ENV_FILE.read_text(encoding="utf-8").splitlines():
            line = raw.strip()
            if not line or line.startswith("#") or "=" not in line:
                continue
            key, value = line.split("=", 1)
            values[key.strip()] = value.strip().strip('"').strip("'")
    except Exception as e:
        print(f"⚠️ Could not read .env: {e}")

    return values


def write_env_values(updates):
    """Update or append selected .env values while preserving unrelated lines."""
    existing_lines = []
    seen = set()

    if ENV_FILE.exists():
        existing_lines = ENV_FILE.read_text(encoding="utf-8").splitlines()

    new_lines = []
    for raw in existing_lines:
        line = raw.strip()

        if not line or line.startswith("#") or "=" not in line:
            new_lines.append(raw)
            continue

        key, _value = line.split("=", 1)
        key = key.strip()

        if key in updates:
            new_lines.append(f"{key}={updates[key]}")
            seen.add(key)
        else:
            new_lines.append(raw)

    for key, value in updates.items():
        if key not in seen:
            new_lines.append(f"{key}={value}")

    ENV_FILE.write_text("\n".join(new_lines).rstrip() + "\n", encoding="utf-8")
    try:
        ENV_FILE.chmod(0o600)
    except Exception:
        pass

    for key, value in updates.items():
        os.environ[key] = value


def spotify_credentials_configured():
    """Return True when Spotify app credentials are configured."""
    return bool(os.getenv("SPOTIFY_CLIENT_ID") and os.getenv("SPOTIFY_CLIENT_SECRET"))


def restart_runtime_services_after_env_change():
    """Restart services that need .env values reloaded.

    Use separate sudo calls because sudoers command matching is argument-specific.
    The config service restart is delayed so this HTTP response can finish first.
    """
    subprocess.Popen(
        ["sudo", "systemctl", "restart", "mementoframe-display.service"],
        stdout=subprocess.DEVNULL,
        stderr=subprocess.DEVNULL,
    )
    subprocess.Popen(
        ["sh", "-c", "sleep 2; sudo systemctl restart mementoframe-config.service"],
        stdout=subprocess.DEVNULL,
        stderr=subprocess.DEVNULL,
    )


def ensure_flask_secret_key():
    """Return a stable Flask session secret, creating and saving one when missing."""
    key = os.getenv("FLASK_SECRET_KEY")
    if key:
        return key

    key = secrets.token_urlsafe(32)

    with open(ENV_FILE, "a", encoding="utf-8") as f:
        f.write(f"\nFLASK_SECRET_KEY={key}\n")

    os.environ["FLASK_SECRET_KEY"] = key
    print("🔐 Generated FLASK_SECRET_KEY and saved it to .env")
    return key


load_dotenv()
app = Flask(__name__)
app.secret_key = ensure_flask_secret_key()

# =============================================================================
# Filesystem layout
# =============================================================================
CONFIG_FILE = "config.json"

USERDATA_DIR = "resources/userdata"
PHOTO_DIR = os.path.join(USERDATA_DIR, "Photos")
FULL_DIR = os.path.join(PHOTO_DIR, "full")
THUMB_DIR = os.path.join(PHOTO_DIR, "thumbs")
PHOTO_TMP_DIR = os.path.join(PHOTO_DIR, "tmp_uploads")
PHOTO_JSON = os.path.join(PHOTO_DIR, "photos.json")
PHOTO_JS = os.path.join(PHOTO_DIR, "photos.js")
CACHE_DIR = os.path.join(USERDATA_DIR, "cache")
SPOTIFY_CACHE = os.path.join(CACHE_DIR, ".cache_spotify")

ASSETS_DIR = "resources/assets"

for d in [USERDATA_DIR, PHOTO_DIR, FULL_DIR, THUMB_DIR, PHOTO_TMP_DIR, CACHE_DIR, ASSETS_DIR]:
    os.makedirs(d, exist_ok=True)

# =============================================================================
# GPIO display and brightness controls
# =============================================================================
SCREEN_PIN = 26
BRIGHTNESS_DOWN = 21
BRIGHTNESS_UP = 20
PRESS_DURATION = 5.5
STEP_DELAY = 0.5

GPIO.setmode(GPIO.BCM)
GPIO.setup(SCREEN_PIN, GPIO.OUT, initial=GPIO.HIGH)
GPIO.setup(BRIGHTNESS_DOWN, GPIO.OUT, initial=GPIO.HIGH)
GPIO.setup(BRIGHTNESS_UP, GPIO.OUT, initial=GPIO.HIGH)
gpio_lock = threading.Lock()

# =============================================================================
# Configuration portal PIN gate
# =============================================================================
RUNTIME_DIR = "runtime"
os.makedirs(RUNTIME_DIR, exist_ok=True)

CONFIG_PORTAL_PIN_FILE = os.path.join(RUNTIME_DIR, "config_portal_pin.json")
CONFIG_PORTAL_ACTIVITY_FILE = os.path.join(RUNTIME_DIR, "config_portal_activity.json")
WIFI_REBOOT_FLAG_FILE = os.path.join(RUNTIME_DIR, "rebooted_for_wifi_failure.flag")
UPDATE_STATE_FILE = os.path.join(RUNTIME_DIR, "update_state.json")
CONFIG_PORTAL_PIN_LENGTH = 6
CONFIG_PORTAL_PIN_TTL_SECONDS = 10 * 60
CONFIG_PORTAL_ACTIVITY_GRACE_SECONDS = 5 * 60

CONFIG_PORTAL_PIN_EXEMPT_ENDPOINTS = {
    "config_portal_pin_page",
    "config_portal_pin_submit",
    "static",
    "serve_assets",
    "health_check",
}


def _atomic_write_json(path, data):
    """Write JSON through a temporary file and atomically replace the target path."""
    directory = os.path.dirname(os.path.abspath(path))
    os.makedirs(directory, exist_ok=True)
    fd, tmp = tempfile.mkstemp(prefix=f".{os.path.basename(path)}.", suffix=".tmp", dir=directory)
    try:
        with os.fdopen(fd, "w", encoding="utf-8") as f:
            json.dump(data, f, indent=2)
            f.flush()
            os.fsync(f.fileno())
        os.replace(tmp, path)
    finally:
        try:
            os.remove(tmp)
        except FileNotFoundError:
            pass



def mark_config_portal_active(reason="dashboard"):
    """Tell the network watchdog to keep AP mode stable for a short window."""
    now = time.time()
    record = {
        "reason": reason,
        "last_seen": now,
        "quiet_until": now + CONFIG_PORTAL_ACTIVITY_GRACE_SECONDS,
        "grace_seconds": CONFIG_PORTAL_ACTIVITY_GRACE_SECONDS,
    }

    try:
        _atomic_write_json(CONFIG_PORTAL_ACTIVITY_FILE, record)
        os.chmod(CONFIG_PORTAL_ACTIVITY_FILE, 0o600)
    except Exception as e:
        print(f"⚠️ Could not write config portal activity marker: {e}")


def clear_wifi_reboot_flag():
    """Allow a future one-shot Wi-Fi recovery reboot after Wi-Fi is healthy."""
    try:
        os.remove(WIFI_REBOOT_FLAG_FILE)
    except FileNotFoundError:
        pass
    except Exception as e:
        print(f"⚠️ Could not clear Wi-Fi reboot flag: {e}")


def remove_config_portal_pin():
    """Delete the active configuration portal PIN file when it exists."""
    try:
        os.remove(CONFIG_PORTAL_PIN_FILE)
    except FileNotFoundError:
        pass
    except Exception as e:
        print(f"⚠️ Could not remove config portal PIN: {e}")


def read_config_portal_pin_record():
    """Read and validate the short-lived configuration portal PIN record."""
    try:
        with open(CONFIG_PORTAL_PIN_FILE, "r", encoding="utf-8") as f:
            record = json.load(f)
    except FileNotFoundError:
        return None
    except Exception:
        remove_config_portal_pin()
        return None

    expires_at = float(record.get("expires_at") or 0)
    pin = str(record.get("pin") or "").strip()
    if not pin or not expires_at or time.time() >= expires_at:
        remove_config_portal_pin()
        return None
    return record


def create_config_portal_pin():
    """Create a new numeric PIN record and schedule automatic expiry cleanup."""
    now = time.time()
    pin = "".join(secrets.choice("0123456789") for _ in range(CONFIG_PORTAL_PIN_LENGTH))
    record = {
        "pin": pin,
        "created_at": now,
        "expires_at": now + CONFIG_PORTAL_PIN_TTL_SECONDS,
        "ttl_seconds": CONFIG_PORTAL_PIN_TTL_SECONDS,
    }
    _atomic_write_json(CONFIG_PORTAL_PIN_FILE, record)
    try:
        os.chmod(CONFIG_PORTAL_PIN_FILE, 0o600)
    except Exception:
        pass

    def expire_pin(expected_pin=pin, expected_expires_at=record["expires_at"]):
        """Remove the generated PIN after its TTL when it has not been replaced."""
        time.sleep(CONFIG_PORTAL_PIN_TTL_SECONDS)
        current = read_config_portal_pin_record()
        if current and current.get("pin") == expected_pin and current.get("expires_at") == expected_expires_at:
            remove_config_portal_pin()

    threading.Thread(target=expire_pin, daemon=True).start()
    return record


def get_or_create_config_portal_pin_record():
    """Return the active PIN record, creating one when none is valid."""
    return read_config_portal_pin_record() or create_config_portal_pin()


def config_portal_pin_gate_required():
    """Report whether the current session still needs PIN verification."""
    return session.get("config_unlocked") is not True


def wake_screen():
    """Set the screen GPIO pin high so the user can see the PIN prompt."""
    try:
        GPIO.setup(SCREEN_PIN, GPIO.OUT, initial=GPIO.HIGH)
        GPIO.output(SCREEN_PIN, GPIO.HIGH)
    except Exception as e:
        print(f"⚠️ Could not wake screen: {e}")


@app.before_request
def enforce_config_portal_pin_gate():
    """Redirect locked sessions to the PIN page before protected routes run."""
    if request.endpoint in CONFIG_PORTAL_PIN_EXEMPT_ENDPOINTS:
        return None
    if config_portal_pin_gate_required():
        wake_screen()
        get_or_create_config_portal_pin_record()
        return redirect(url_for("config_portal_pin_page"))
    return None


@app.route("/config-portal-pin", methods=["GET"])
def config_portal_pin_page():
    """Display the PIN entry page and ensure a valid PIN exists."""
    wake_screen()
    get_or_create_config_portal_pin_record()
    return render_template("pin.html", error=None)


@app.route("/config-portal-pin", methods=["POST"])
def config_portal_pin_submit():
    """Validate a submitted PIN and unlock the configuration portal session."""
    record = read_config_portal_pin_record()
    submitted = request.form.get("pin", "").strip()
    if record and submitted == record.get("pin"):
        session["config_unlocked"] = True
        remove_config_portal_pin()
        return redirect(url_for("dashboard"))

    wake_screen()
    get_or_create_config_portal_pin_record()
    return render_template("pin.html", error="Incorrect or expired PIN — try again.")


# =============================================================================
# Photo metadata and image helpers
# =============================================================================
def build_photo_list():
    """Return sorted supported image filenames from the full-size photo directory."""
    exts = (".jpg", ".jpeg", ".png", ".gif", ".bmp", ".webp")
    return sorted([f for f in os.listdir(FULL_DIR) if f.lower().endswith(exts)])

def load_photos():
    """Load the photo ordering file, rebuilding it from disk when missing or invalid."""
    if not os.path.exists(PHOTO_JSON):
        photos = build_photo_list()
        save_photos(photos)
        return photos
    try:
        with open(PHOTO_JSON) as f:
            photos = json.load(f)
        if not photos:
            photos = build_photo_list()
            save_photos(photos)
        return photos
    except Exception:
        photos = build_photo_list()
        save_photos(photos)
        return photos

def save_photos(photos):
    """Persist the photo list and synchronize the browser-facing JavaScript file."""
    with open(PHOTO_JSON, "w") as f:
        json.dump(photos, f, indent=2)
    sync_photo_js(photos)

def sync_photo_js(photos=None):
    """Write the current photo list as a JavaScript global for the frame UI."""
    if photos is None:
        photos = load_photos()
    js_content = "window.photos = " + json.dumps(photos, indent=2) + ";"
    with open(PHOTO_JS, "w") as f:
        f.write(js_content)


photo_processing_lock = threading.Lock()
photo_processing_status_lock = threading.Lock()
photo_processing_status = {
    "active": False,
    "queued": 0,
    "processed": 0,
    "failed": 0,
    "last_batch_id": None,
    "last_error": None,
    "updated_at": None,
}


def update_photo_processing_status(**updates):
    """Update the in-memory photo-processing status exposed to the config portal."""
    with photo_processing_status_lock:
        photo_processing_status.update(updates)
        photo_processing_status["updated_at"] = time.time()


def get_photo_processing_status():
    """Return a copy of the current background photo-processing status."""
    with photo_processing_status_lock:
        return dict(photo_processing_status)


def unique_temp_upload_path(batch_dir, filename):
    """Return a collision-safe temporary upload path inside one batch directory."""
    name, ext = os.path.splitext(filename)
    counter = 1
    candidate = os.path.join(batch_dir, filename)
    while os.path.exists(candidate):
        candidate = os.path.join(batch_dir, f"{name}_{counter}{ext}")
        counter += 1
    return candidate


def unique_final_photo_name(original_filename, photos):
    """Return a collision-safe final filename for the processed photo."""
    name, ext = os.path.splitext(original_filename)
    if not name:
        name = f"photo_{uuid.uuid4().hex[:8]}"

    counter = 1
    webp_name = f"{name}.webp"
    while webp_name in photos or os.path.exists(os.path.join(FULL_DIR, webp_name)):
        webp_name = f"{name}_{counter}.webp"
        counter += 1
    return webp_name


def unique_fallback_photo_name(original_filename, photos):
    """Return a collision-safe fallback filename when image conversion fails."""
    name, ext = os.path.splitext(original_filename)
    ext = ext or ".bin"
    if not name:
        name = f"photo_{uuid.uuid4().hex[:8]}"

    candidate = f"{name}{ext}"
    counter = 1
    while candidate in photos or os.path.exists(os.path.join(FULL_DIR, candidate)):
        candidate = f"{name}_{counter}{ext}"
        counter += 1
    return candidate


def process_uploaded_photo_batch(batch_id, batch_dir):
    """Convert queued uploads to final WebP photos without blocking the request."""
    processed = 0
    failed = 0

    with photo_processing_lock:
        update_photo_processing_status(
            active=True,
            last_batch_id=batch_id,
            last_error=None,
        )

        try:
            temp_files = [
                os.path.join(batch_dir, name)
                for name in sorted(os.listdir(batch_dir))
                if os.path.isfile(os.path.join(batch_dir, name))
            ]
        except FileNotFoundError:
            update_photo_processing_status(active=False, last_error="Upload batch directory disappeared.")
            return

        photos = load_photos()

        for temp_path in temp_files:
            filename = os.path.basename(temp_path)
            webp_name = unique_final_photo_name(filename, photos)
            full_path = os.path.join(FULL_DIR, webp_name)
            thumb_path = os.path.join(THUMB_DIR, webp_name)

            try:
                with Image.open(temp_path) as img:
                    img = ImageOps.exif_transpose(img).convert("RGB")

                    full_img = img.copy()
                    full_img.thumbnail((1000, 1000))
                    full_img.save(full_path, format="WEBP", quality=100, method=6)

                    thumb = img.copy()
                    thumb.thumbnail((250, 250))
                    thumb.save(thumb_path, format="WEBP", quality=80, method=6)

                os.remove(temp_path)
                photos.append(webp_name)
                processed += 1
                update_photo_processing_status(processed=processed, failed=failed)

            except Exception as e:
                failed += 1
                update_photo_processing_status(processed=processed, failed=failed, last_error=str(e))
                print(f"Error processing queued upload {filename}: {e}")

                try:
                    fallback_name = unique_fallback_photo_name(filename, photos)
                    fallback_full = os.path.join(FULL_DIR, fallback_name)
                    os.replace(temp_path, fallback_full)
                    photos.append(fallback_name)
                except Exception as fallback_error:
                    print(f"Error saving fallback upload {filename}: {fallback_error}")
                    try:
                        os.remove(temp_path)
                    except FileNotFoundError:
                        pass

        save_photos(photos)

        try:
            os.rmdir(batch_dir)
        except OSError:
            pass

        update_photo_processing_status(
            active=False,
            queued=0,
            processed=processed,
            failed=failed,
        )

# =============================================================================
# Network helpers
# =============================================================================
def _run(cmd, timeout=None):
    """Run a subprocess command and return its status, stdout, and stderr."""
    try:
        proc = subprocess.run(cmd, capture_output=True, text=True, timeout=timeout)
        return proc.returncode, proc.stdout.strip(), proc.stderr.strip()
    except subprocess.TimeoutExpired as e:
        return 124, (e.stdout or "").strip() if isinstance(e.stdout, str) else "", "command timed out"
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

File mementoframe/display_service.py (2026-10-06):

#!/usr/bin/env python3
# MementoFrame - Raspberry Pi Smart Photo Frame
# Copyright (c) 2026 João Fernandes
#
# This work is licensed under the Creative Commons Attribution-NonCommercial
# 4.0 International License. To view a copy of this license, visit:
# http://creativecommons.org/licenses/by-nc/4.0/

"""
api_service.py

Brief:
    Local display API for MementoFrame frontend widgets and hardware controls.

Endpoints:
    GET  /                         - Render the photo-frame frontend.
    GET  /assets/<filename>        - Serve static project assets.
    GET  /userdata/<filename>      - Serve persistent user data files.
    GET  /config.json              - Serve saved frame configuration.
    GET  /spotify.json             - Return current Spotify playback metadata.
    GET  /weather.json             - Return current weather data.
    POST /weather/refresh          - Reload weather settings and fetch fresh data.
    GET  /config_portal_pin.json   - Return active AP-mode PIN for local display UI.
    GET  /status.json              - Return Wi-Fi/AP mode, IP address, and uptime.
    GET  /health                   - Return service health status.
    GET  /get_ip                   - Return detected local IP address.
    GET  /versions                 - Return installed component versions.
    GET  /config/stream            - Server-Sent Events stream for config/photo reloads.
    POST /screen/on                - Turn the display output on.
    POST /screen/off               - Turn the display output off.

"""
import sys
import threading

from flask import Flask, jsonify, render_template, send_from_directory, Response
from flask_cors import CORS
import os, json, time, socket, threading, subprocess, requests, datetime
from dotenv import load_dotenv
import spotipy
from spotipy.oauth2 import SpotifyOAuth
import RPi.GPIO as GPIO
from updater import PROJECT_ROOT
from version_info import GLOBAL_APP_VERSION, VERSION_INFO


# =============================================================================
# Hardware setup
# =============================================================================
SCREEN_PIN = 26
GPIO.setwarnings(False)
GPIO.setmode(GPIO.BCM)
GPIO.setup(SCREEN_PIN, GPIO.OUT, initial=GPIO.HIGH)

# =============================================================================
# Flask initialization
# =============================================================================
load_dotenv()
app = Flask(__name__, static_folder="static", static_url_path="/static")
CORS(app)

# =============================================================================
# Filesystem layout
# =============================================================================
CONFIG_FILE = "config.json"

USERDATA_DIR = "resources/userdata"
ASSETS_DIR = "resources/assets"
PHOTO_JSON = os.path.join(USERDATA_DIR, "Photos/photos.json")
SPOTIFY_CACHE = os.path.join(USERDATA_DIR, "cache/.cache_spotify")
GOOGLE_WEATHER_CACHE_FILE = os.path.join(USERDATA_DIR, "cache/google_weather.json")
RUNTIME_DIR = "runtime"
CONFIG_PORTAL_PIN_FILE = os.path.join(RUNTIME_DIR, "config_portal_pin.json")
UPDATE_STATE_FILE = os.path.join(RUNTIME_DIR, "update_state.json")
UPDATE_ACTIVE_PHASES = {
    "applying", "awaiting_reboot", "verifying", "rolling_back",
    "awaiting_rollback_reboot", "verifying_rollback",
}
_update_state_cache = {}
_update_state_cache_lock = threading.Lock()

# =============================================================================
# Configuration loading
# =============================================================================
def load_config():
    """Load config.json for display-service runtime settings."""
    if not os.path.exists(CONFIG_FILE):
        return {}
    try:
        with open(CONFIG_FILE, "r") as f:
            return json.load(f)
    except Exception as e:
        print(f"Error loading config.json: {e}")
        return {}


def load_update_state():
    """Return updater runtime state merged with config/update defaults for display UI."""
    state = {}
    state_valid = True
    state_read_error = None
    try:
        with open(UPDATE_STATE_FILE, "r", encoding="utf-8") as f:
            state = json.load(f)
        if not isinstance(state, dict):
            raise ValueError("update state must be a JSON object")
    except FileNotFoundError:
        state_valid = False
        state_read_error = "Update state file is temporarily unavailable."
    except Exception as e:
        state_valid = False
        state_read_error = f"Unable to read update state: {e}"

    with _update_state_cache_lock:
        if state_valid:
            _update_state_cache.clear()
            _update_state_cache.update(state)
        elif (
            _update_state_cache.get("update_in_progress")
            or _update_state_cache.get("pending_restart")
            or _update_state_cache.get("reboot_requested")
            or _update_state_cache.get("rollback_in_progress")
            or _update_state_cache.get("rollback_reboot_requested")
            or _update_state_cache.get("update_phase") in UPDATE_ACTIVE_PHASES
        ):
            # A missing/corrupt sample is not authoritative while an update is
            # active. Keep the last valid lifecycle instead of flashing idle.
            state = dict(_update_state_cache)
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

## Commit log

2026-03-13 changed readme and added photos and wiring section
2026-04-19 some changes to the ap_mode_manager to fix wifi issues (in testing). | added versioning to the project
    [app.py, version_info.py]
2026-05-05 Changes to ap mode manager: NM own both modes entirely, switching between two profiles
2026-05-06 reworked wifi connection flow, added config pin generation and management for config page
    [api_service.py, app.py, version_info.py]
2026-05-08 app.py didn't get commited in the last version.
    [app.py, version_info.py]
2026-05-10 Fix styling on the image if its vertical, rounded corners and positioning.
    [version_info.py]
2026-05-11 started work on updater module, which will check for updates and notify the user if an update is available. This will be a new feature that will allow users to easily keep their MementoFrame installa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
    [api_service.py, app.py, version_info.py]
2026-05-12 update to updater to be compatible with the current folder structure
2026-05-12 fixes to the update check logic
    [api_service.py, updater.py, version_info.py]
2026-05-12 updater fix to preserve user data
    [api_service.py, updater.py]
2026-05-12 fixes to the updater
    [updater.py, version_info.py]
2026-05-14 Refactor services and versioning for first release
    - Rename runtime services for clearer responsibilities:
    - app.py -> config_portal_service.py
    - api_service.py -> display_service.py
    - ap_mode_manager.py -> network_manager_service.py
    - Split startup into dedicated systemd services for config portal, display API, network manager, kiosk, and post-reboot checks
    - Remove legacy start_apps.sh combined launcher
    - Add requirements.txt for Python dependencies
    - Update updater service handling for the new split-service layout
    - Add composite release versioning based on release counter and component versions
    - Update loading screen to display the single global MementoFrame version
    - Update Spoti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
    [config_portal_service.py, display_service.py, network_manager_service.py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]
2026-05-15 spotify album cover: fix to wait before showing to prevent placeholder from appearing.
    [version_info.py]
2026-05-15 mock updates to be compatible with current release, small spotify fix
    [version_info.py]
2026-05-15 Config portal styling update and photo upload reworked
    [config_portal_service.py, version_info.py]
2026-05-17 small fix for photo bursts | on my display this still causes screen tearing so looking for new options
    [version_info.py]
2026-05-18 small fix to the new burstPhotos animation
    [version_info.py]
2026-05-18 small fix on previous implementation
    [version_info.py]
2026-05-18 Fix for photo positioning when showCalendarFull is active and Spotify is playing. Also added showCalendarFull and hideCalendarFull to window for use in layout.js and calendar.js.
    [version_info.py]
2026-05-18 small fix, vertical photo clipped when swapping panels
    [version_info.py]
2026-05-18 so changes to the padding around the frame.
2026-05-22 rework on photoslideshow: better randomization to make sure all photos are shown before shuffling the array
    [version_info.py]
2026-05-25 small fixes for uv index patch
    [display_service.py, version_info.py]
2026-05-25 Frontend: weather: if multiple alerts are available, rotate them on the 1 minute window (every 5 minutes) | display_service: Filter alerts for current area only.
2026-05-29 updater overlay small fix | spotify first play fix | qr code new accent | system info box rework | css cleanup
    [config_portal_service.py, display_service.py, version_info.py]
2026-05-29 bugfix: update flag visibility when there are no updates available
    [version_info.py]
2026-06-02 keep wifi symbol visible when pin is shown
2026-06-11 ### Changed - Unified kiosk widget panel materials through shared CSS variables for light/dark photo modes. - Kept panel backgrounds darker for vertical photos, burst layouts, and narrowed big/Spotif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
2026-06-13 Release Notes v5.51.27.28.22.17 Frontend Improved the Spotify player visual design with album-art-aware gradient backgrounds. Extracts two colours from the current Spotify album art instead of fading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
    [version_info.py]
2026-06-29 Release Notes Spotify Playback & Display Improvements Bug Fixes:
    Fixed accent color not re-extracting on song resume
    When resuming a paused song after 30+ seconds, the album art accent color now properly re-extracts instead of using stale cached colors
    Root cause: Old artwork key comparison prevented re-rendering of same-song artwork on resume
    Fix: Clear artwork render token in cancelArtworkRender() to force fresh extraction
    Weather Alerts UI Improvements
    Changes:
    Removed redundant severity text from weather alert displays
    Before: ⚠ Moderate: Wind Advisory
    After: ⚠ Wind Advisory
    Added color-coded warning icons for alert severity levels
    🟨 Minor - Amber (#FFC107)
    🟧 Moderate - Or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
2026-08-06 Documentation and Hardware Update This PR expands and reorganizes the MementoFrame documentation to cover the complete hardware build and local development workflow. What changed Reorganized the READ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
    [back_cover.stl, display_holder.stl, electronics_holder.stl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]
2026-08-06 Documentation, Hardware, and Development Update This PR significantly expands and reorganizes the MementoFrame documentation, covering the physical build, frontend layouts, software installation, and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
    Added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
2026-08-06 Frame and assembly documentation Added the store-bought wooden frame to the BOM. Corrected the nominal frame format to 130 × 180 mm (13 × 18 cm, approximately 5 × 7 inches). Documented the approximat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
2026-08-06 Improves INSTALL.md with a clearer end-to-end installation and configuration guide. Changes Separated automatic install.sh installation from the advanced manual process. Added a structured post-insta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
2026-08-06 Frontend version bump to reflecth the fix made to spotify player resume playback album extraction
    [version_info.py]
2026-08-06 Weather Refresh and Dynamic Layout Improvements Weather Added a Refresh Weather Now button to the configuration dashboard. Weather refreshes immediately after saving the API key or region. Added succ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
    [config_portal_service.py, display_service.py, version_info.py]
2026-08-18 MementoFrame v6.56.30.29.22.17 Configuration dashboard - Completely redesigned configuration dashboard. - Added a cleaner, responsive control-center layout. - Added sticky section navigation for fast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
    [config_portal_service.py, version_info.py]
2026-08-19 Weather API usage - Reduced frontend weather polling from every 30 minutes to once per hour. - Added independent Google Weather caching: - Current conditions: 1 hour - Hourly forecast: 1 hour - Five-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
    [version_info.py]
2026-08-26 feat(ui): enhance clock, weather, and compact widget layouts Commit notes - Add configurable 12/24-hour clock format with compact AM/PM suffixes. - Animate individual clock digit changes. - Improve d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
2026-10-05 Network Recovery Fixed AP fallback startup when no Wi-Fi is available at boot. Removed network-online.target dependency from local MementoFrame services so the network watchdog can start even while o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
    [config_portal_service.py, network_manager_service.py, updater.py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]
2026-10-05 some fixes on the frontend style for the classic theme
    [updater.py, version_info.py]
2026-10-05 some bug fixes on the updater
    [updater.py, version_info.py]
2026-10-05 some frontend fixes and improvements to the config portal
    [display_service.py, version_info.py]
2026-10-05 some fixes to the updater portion. Update overlay should stay visible until restart and while the update is being checked. If theres a rollback it also shows that on the overlay
    [config_portal_service.py, display_service.py, updater.py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]
2026-10-05 upadter.py now preserves active update/reboot/rollback state across unrelated replace_state() refreshes, which should stop the overlay from disappearing mid-apply. ]updater.js now keeps the text as “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
    [updater.py, version_info.py]
2026-10-06 added a new theme classic-flat, its the classic but without the coloured borders.
    Fixed the height of the weather divs when they are showing the 5h or 5d forecast.
    [config_portal_service.py]
2026-10-06 update overlay fixes and improvements, including post-reboot health checks
    [version_info.py]
2026-10-12 # MementoFrame v6.68.34.35.24.25
    12 October 2026
    This release improves fallback access point recovery when saved Wi-Fi networks are unavailable and prevents repeated recovery reboots.
    ## AP recovery
    - Fixed reconnect probes restarting immediately after the AP was restored. The AP now receives a full two-minute idle interval before the next probe.
    - Shortened reconnect attempts by removing the extra wait after a saved network fails to connect and adding command timeouts.
    - Restores the AP when a reconnect probe encounters an error.
    - Loading the dashboard no longer delays starting a missing AP. Active AP clients and dashboard sessions still defer idle reconnect probes.
    - Verifies that the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
2026-11-09 This release moves screen power scheduling into the display backend and adds automatic recovery when the Chromium kiosk stops responding.
    ## Screen power and kiosk recovery
    - The existing display service now owns screen scheduling and GPIO 26. Scheduling follows clock 1's timezone and continues when the browser fails.
    - The initialized local frontend sends a token-protected heartbeat every 10 seconds, including while the screen is scheduled off. Remote frontend sessions cannot keep the kiosk watchdog healthy.
    - Startup includes a two-minute grace period followed by a 60-second missing-heartbeat timeout. Recovery cannot begin before three minutes after the display service starts.
    - The scree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

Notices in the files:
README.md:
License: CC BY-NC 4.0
